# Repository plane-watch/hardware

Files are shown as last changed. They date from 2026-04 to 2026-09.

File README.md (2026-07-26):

# Plane Watch hardware

Open hardware designs from Plane Watch for receiving and decoding aircraft surveillance signals.

<div style="text-align: center;">Open Source Hardware Logo</div>

## Hardware projects

| Project | Preview Image | Description |
| --- | --- | --- |
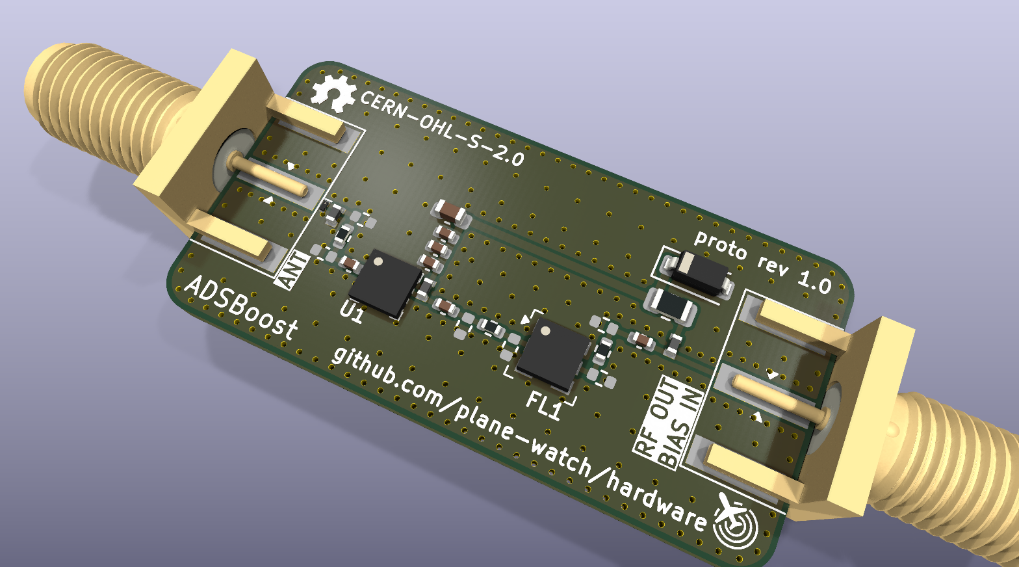
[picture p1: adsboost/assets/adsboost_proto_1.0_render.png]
3D render of the ADSBoost prototype revision 1.0 PCB
| [ADSBoost](adsboost/README.md) |  | A receive-only, bias-tee-powered low-noise amplifier and SAW filter module for 1,090 MHz ADS-B and Mode S reception. ADSBoost is designed to be installed close to the antenna; the current prototype is awaiting assembly and performance testing. |
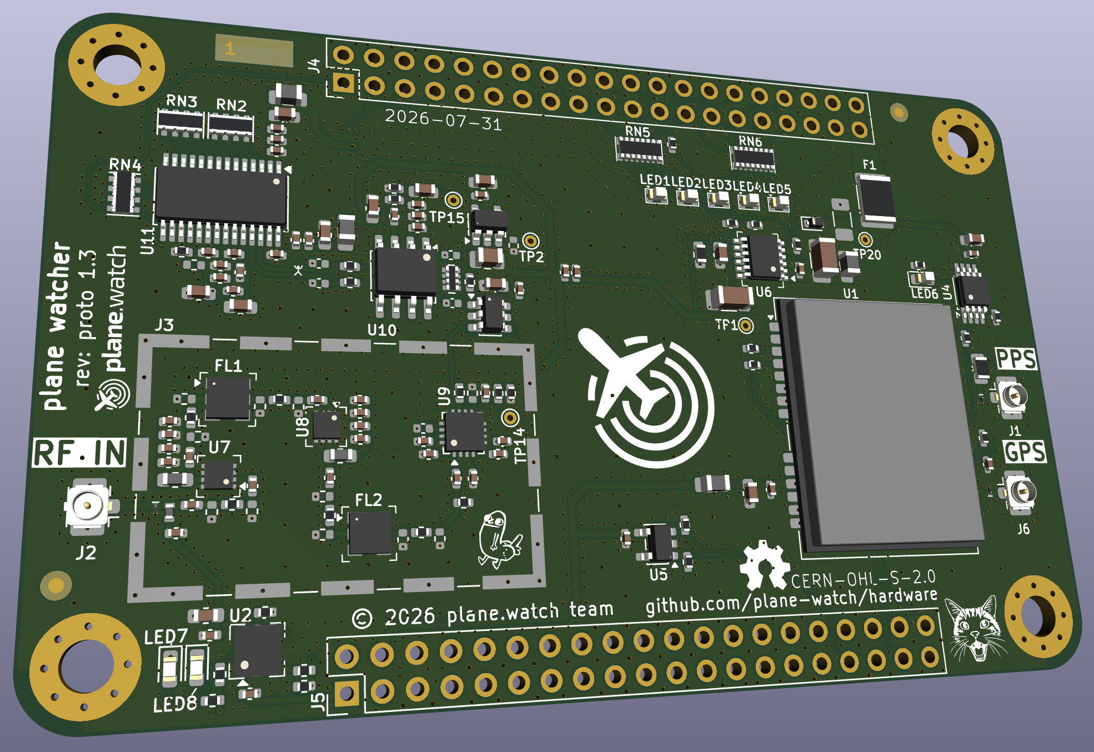
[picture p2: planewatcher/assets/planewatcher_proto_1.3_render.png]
3D render of the Plane Watcher prototype revision 1.3 PCB
| [Plane Watcher](planewatcher/README.md) |  | An open source, hardware-based ADS-B receiver and decoder for the HelloFPGA Smart ZYNQ SL. Plane Watcher combines a dual-stage RF front end, log detector, ADC and GNSS timing to support FPGA message decoding and accurate MLAT timestamping. |

## License

Unless a project or file explicitly states otherwise, all original hardware design files in this repository are licensed under the [CERN Open Hardware Licence Version 2 – Strongly Reciprocal (CERN-OHL-S-2.0)](LICENSE).

The CERN-OHL-S-2.0 permits commercial use, but its reciprocal requirements apply when covered source or products based on it are distributed. Alternative commercial licensing is available for organisations that need different terms.

In short: you may use and modify the designs privately. If you distribute modified source or products based on them, the CERN-OHL-S-2.0 requirements apply.

## Third-party materials disclaimer

This repository may include third-party datasheets, application notes and other technical documentation. These materials remain the copyright of their respective owners, are not covered by the repository's hardware licence, and are included solely to assist development and interoperability of the hardware projects.

If you are a copyright holder and have concerns about material included here, please open an issue or contact the maintainers.

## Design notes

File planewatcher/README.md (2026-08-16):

# plane watcher

Render of Plane Watcher PCB, prototype revision 1.3

The **plane watcher** is our attempt at creating an open source, hardware-based ADS-B receiver and decoder. It is a hat/cape/shield for a [HelloFPGA Smart ZYNQ SL](http://www.hellofpga.com/index.php/2023/05/10/smart-zynq-sl/) board.

The goal of the project is to make a reasonably priced yet high-quality ADS-B receiver for hobbyists. It is designed to support accurate MLAT timestamping using GNSS timing and message decoding in the FPGA.

This repository contains the hardware design. The FPGA gateware and software live in the [plane-watch/plane-watcher](https://github.com/plane-watch/plane-watcher) repository.

<div style="text-align: center;">Open Source Hardware Logo</div>

## Status

Proto 1.2 is the latest fabricated and tested revision. Proto 1.3 is still being refined and has not yet been fabricated or validated.

### Proto 1.2

The first fabricated prototype worked, but had a few issues:

- The SMA connector for the 1,090 MHz RF input fouled on the RJ45 Ethernet connector of the FPGA board. For proto 1.3, the RF and GPS antenna connectors have been swapped to U.FL. We will use pigtails to panel-mount SMA connectors.
- The ADL5513 log-detector output was not strong enough to drive the AD8138 ADC driver gain/feedback network directly. Increasing the gain/feedback resistor values from 499 Ω to 4.7 kΩ fixed this on the prototype. In proto 1.3, the ADL5513 output is also buffered.
- We did not have component footprints to tweak the ADL5513 output slope. These have been added to proto 1.3 to allow further refinement if required.
- The 1PPS LED was way too bright on the prototype, so this has been dimmed for proto 1.3.
- The ADL5513 TADJ trimmer network was too high impedance (I should've read the data sheet better) and did not appear to make any difference whatsoever. This has been replaced with a simple voltage divider set to around 0.86 V, in line with the datasheet guidance.

Regardless of the issues, we observed a reception range of approximately 320 km.

Animated GIF showing proto 1.2 in operation with blinky LEDs

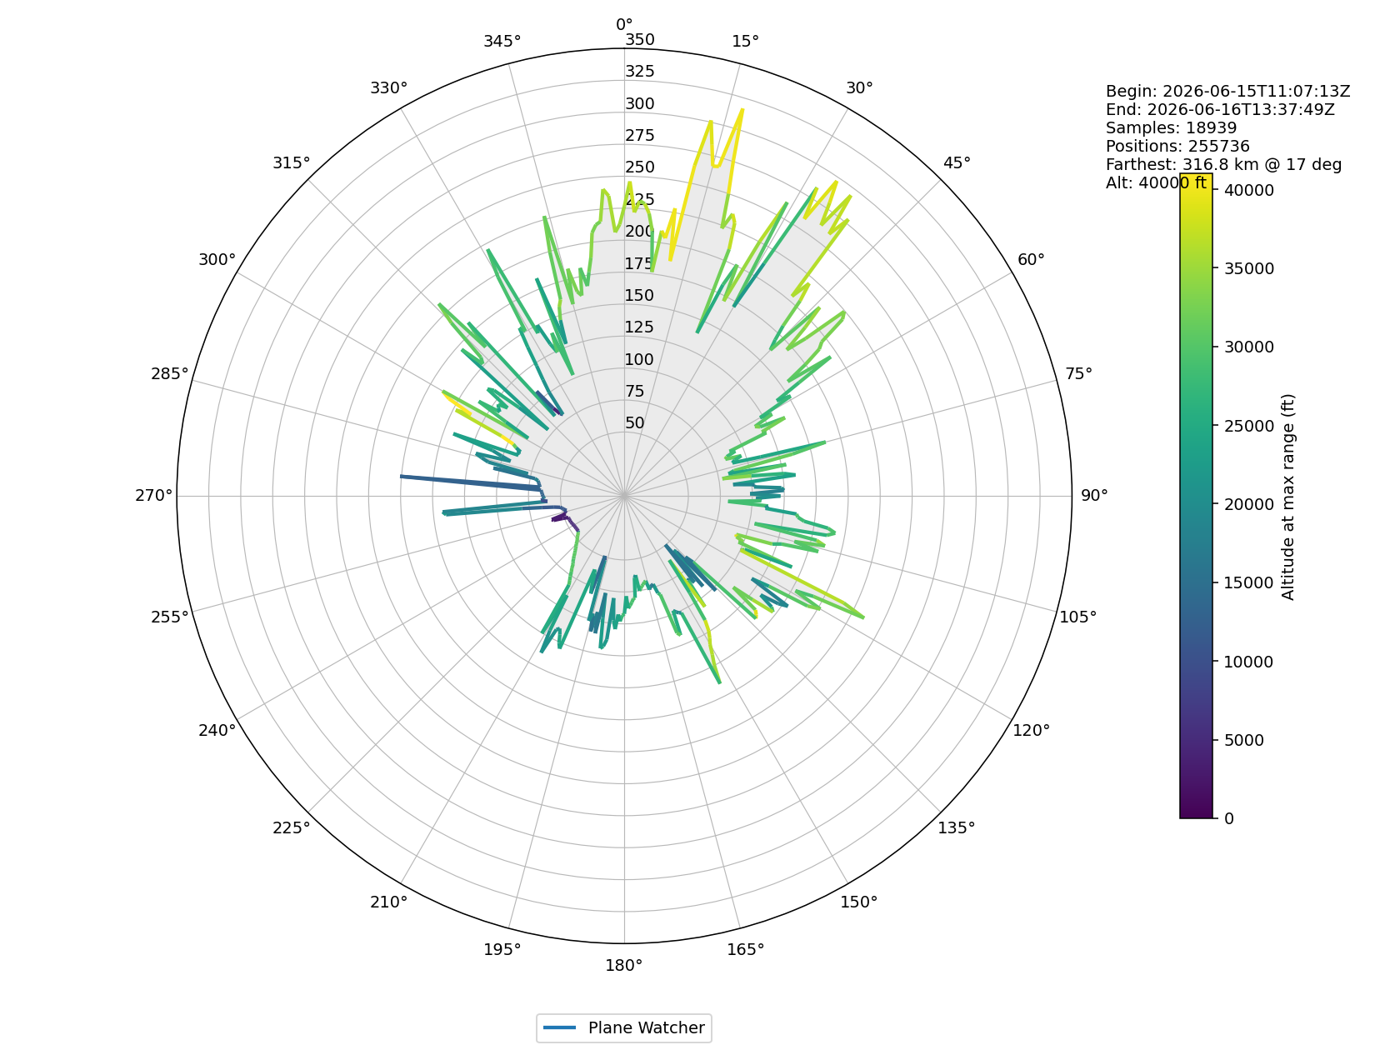
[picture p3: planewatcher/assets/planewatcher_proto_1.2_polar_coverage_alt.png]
Polar range diagram from proto 1.2


### Proto 1.3

In addition to fixing the issues above, proto 1.3 includes some functionality and layout changes:

- More unpopulated component footprints have been added to allow tweaking/refinement:
  - ADL5513 log-detector slope adjustment voltage divider.
  - AD8138 ADC driver feedback capacitors.
  - Five 0402 pi-pad matching networks along the RF path: one on each side of both LNA stages, and one at the ADL5513 RF input. These are fitted as straight-through links by default, with a 0 Ω series resistor and both shunt positions left unpopulated. After measuring the assembled board with a VNA, the footprints can be populated with suitable resistor, capacitor or inductor values to refine the 1,090 MHz matching and compensate for real-world PCB and component parasitics.
  - Other tweaking footprints along the ADC signal path.
- The ADL5513 log-detector output is buffered by a high-speed ADA4807-1 op-amp for more robust operation with weak signals, and to decouple it from the AD8138 input network.
- The buffered log-detector output is also fed into a first-order low-pass filter at approximately 0.072 Hz to produce a slow-moving analog baseline. This heavily attenuates short ADS-B pulse bursts, but sustained RF traffic can still affect the baseline. The baseline is buffered by an OPA320 and applied to the AD8138 ADC driver input network, offsetting the detector output before digitisation and improving the usable ADC range for weak pulses.
- RF_IN and GPS antenna connectors have been swapped from SMA to U.FL.
- A software-controlled bias tee has been added. This can supply around 4.5 V to the RF_IN connector, current-limited to approximately 300 mA. LEDs have been added to show whether bias tee is enabled/disabled, and to show if overcurrent disable has been activated.
- A GNSS-disciplined 1PPS timing output has been added. This is a buffered copy of the LEA-M8T TIMEPULSE signal, provided on a 50 Ω source-terminated U.FL connector. The centre pin carries an active-high pulse and the shell is connected to ground. The output is approximately 0 to 4.5 V into a high-impedance load, or approximately 0 to 2.2 V into a 50 Ω terminated load. The rising edge should be treated as the timing reference.
- Some discrete resistors have been replaced with resistor arrays to reduce the BoM and make hand assembly easier.
- The ADC supply, reference and VOCM networks have been reworked in an attempt to reduce noise, including additional bypassing, ferrite isolation and improved grounding.
- Selectable REFSENSE links allow the ADC input range to be configured for 1 Vpp or 2 Vpp.
- PCB grounding and sensitive-node isolation have been revised with additional via stitching, shorter reference routing and copper keepouts.
- Additional high-frequency bypassing has been added to keep the bias-tee supply side at RF ground.
- Re-routed ADC input differential pair to remove vias/crossovers & remove skew. The ADC output will need to be negated in software.

## Hardware overview

The proto 1.3 design has the following main components and interfaces:

| Function | Implementation |
| --- | --- |
| RF input | 1,090 MHz ADS-B, U.FL connector |
| RF front end | Two LNA and SAW filter stages |
| Log detector | ADL5513 |
| Baseband buffers | ADA4807-1 fast-path buffer and OPA320 slow-baseline buffer |
| ADC driver | AD8138 |
| ADC | AD9203, 10-bit, up to 40 MSPS |
| GNSS timing | LEA-M8T with FPGA and external 1PPS outputs |
| Bias tee | Software-controlled, approximately 4.5 V at 300 mA maximum |
| Local power | LT3045-1 low-noise 3.3 V RF/analog supply |
| FPGA carrier | HelloFPGA Smart ZYNQ SL |

## Design

The design consists of the following parts:

### RF Input

The signal from the antenna is amplified and filtered using two stages of LNA amplification and SAW filters centred on 1,090 MHz.

A switchable bias tee power supply can apply approximately 4.5 V at up to 300 mA to the RF_IN connector.

### Log Detector

The amplified and filtered RF signal is fed into an ADL5513 log detector, which produces a voltage proportional to the logarithm of the RF input power. With an oscilloscope on its output, we can see the raw ADS-B pulses and decode them by hand.

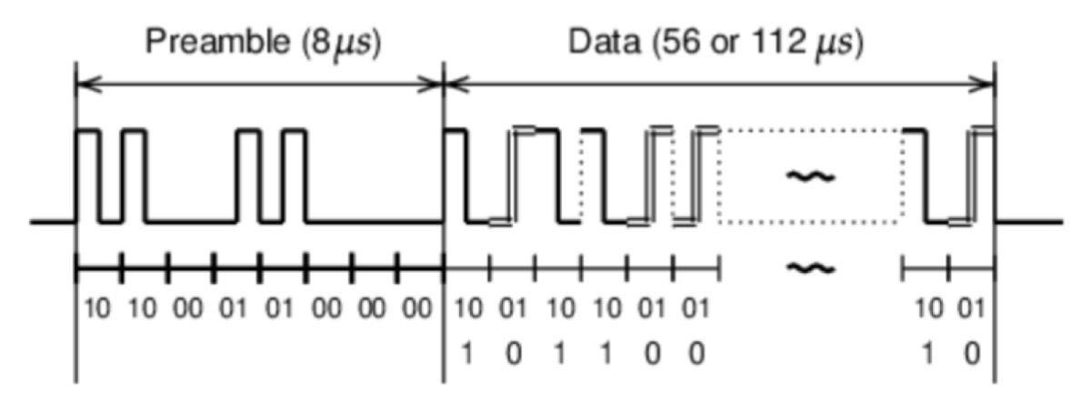
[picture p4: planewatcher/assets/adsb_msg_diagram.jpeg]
ADS-B message example diagram


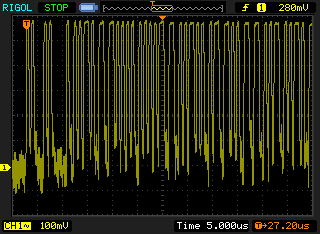
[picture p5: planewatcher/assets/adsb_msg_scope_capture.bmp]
ADS-B message pulses on an oscilloscope


### ADC Driver

The ADL5513 log-detector output is buffered with a high-speed ADA4807-1 op-amp to isolate it from the ADC driver input network and provide a robust baseband signal.

The ADC uses a differential input. To drive it, the buffered baseband signal is split:

- Through the gain/input resistor network into the AD8138 positive input summing node.
- Into a first-order low-pass filter at approximately 0.072 Hz, producing a slow-moving analog baseline with short ADS-B pulse bursts heavily attenuated. This baseline is then buffered by an OPA320 to decouple it from the ADC driver input network and applied through the gain/input resistor network into the AD8138 negative input summing node.

The AD8138 produces a differential output proportional to the difference between the instantaneous log-detector output and the slow noise-floor estimate.

### ADC

The differential output of the ADC driver is fed into an AD9203 10-bit, 40 MSPS ADC. The ADC input range can be configured for 1 Vpp or 2 Vpp using selectable REFSENSE links. After prototyping we will either hard-set this, or make it software controllable. The FPGA supplies the sample clock and receives the digitised output.

### GNSS Timing

The LEA-M8T GNSS timing receiver provides its TIMEPULSE signal to the FPGA for timestamping. Proto 1.3 also buffers this signal for an external, source-terminated 1PPS output and a status LED.

### Power

The board is powered from the approximately 4.5 V FPGA_VCC rail provided by the carrier board (5V from the USB-C connector, through a Schottky diode). The input has resettable overcurrent and transient protection. A ferrite-filtered LT3045-1 linear regulator generates the local low-noise 3.3 V RF/analog supply, with additional ferrite isolation and local bypassing around the ADC.

### FPGA

The FPGA gateware samples the ADC output, detects and timestamps ADS-B pulses, and converts them into usable messages. The gateware and supporting software are developed in the [plane-watch/plane-watcher](https://github.com/plane-watch/plane-watcher) repository.

## Repository contents

- [KiCad project](planewatcher/kicad/planewatcher.kicad_pro)
- [Top-level schematic](planewatcher/kicad/planewatcher.kicad_sch)
- [PCB layout](planewatcher/kicad/planewatcher.kicad_pcb)

The editable design files use KiCad 10. Release-ready manufacturing outputs are not currently included while the proto 1.3 design is still being refined.

## Attributions

- [“1.09 GHz Mode-S Receiver Design and
  VHF Radar Antenna Characterization”, Senior Thesis in Electrical Engineering, Dabin Zhang](https://www.ideals.illinois.edu/items/47640/bitstreams/139976/data.pdf).
- [Project “ADS-B Receiver and Decoder” presentation by Günter Köllner, DL4MEA](https://www.qsl.net/dl4mea/fpgaadsb/Koellner_Projekt-ADSB3.pdf).
- The [Open Source Hardware gear logo](https://oshwa.org/resources/open-source-hardware-logo/) was designed by Macklin Chaffee and is licensed CC-SA.
- “Dickbutt” appears courtesy of [K.C. Green](https://kcgreendotcom.com/). RF performance gains are unverified.

## License

The hardware design files are licensed under the [CERN Open Hardware Licence Version 2 – Strongly Reciprocal (CERN-OHL-S-2.0)](LICENSE).

The CERN-OHL-S-2.0 permits commercial use, but its reciprocal requirements apply when covered source or products based on it are distributed.

Alternative commercial licensing is available for companies that need different terms.

TL;DR: You can use and modify the design privately. If you distribute modified source or products based on it, the CERN-OHL-S-2.0 requirements apply. If those terms do not work for you, talk to us.

## Notice

This repository may include third-party datasheets, application notes, and technical documentation.

Such materials remain the copyright of their respective owners and are included solely to assist development and interoperability of this project.

If you are a copyright holder and have concerns regarding included materials, please open an issue or contact the maintainers.

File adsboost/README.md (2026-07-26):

# ADSBoost

3D render of the ADSBoost prototype revision 1.0 PCB

**ADSBoost** is an open source, receive-only LNA and SAW filter module for 1090 MHz ADS-B and Mode S reception. It is intended to be installed close to the antenna and powered through its RF output coax using a bias tee.

<div style="text-align: center;">Open Source Hardware Logo</div>

## Expected performance

> ADSBoost is currently a prototype. The module-level figures below are design estimates derived from the component datasheets; they are not production-tested. They will be replaced with measured results after the first assembled boards have been characterised.

| Parameter | Expected performance | Notes |
| --- | --- | --- |
| Application | 1090 MHz ADS-B and Mode S reception | Receive only; do not connect the input to a transmitter |
| Centre frequency | 1090 MHz | Set by the TA2003A SAW filter |
| Specified passband | 1087-1093 MHz | 6 MHz nominal filter bandwidth |
| In-band gain | Approximately 15 dB typical | Estimated from approximately 18 dB LNA gain at 1090 MHz minus 3.2 dB typical SAW insertion loss and small PCB losses |
| Noise figure | Approximately 0.5-0.7 dB expected | Estimate including the input network; measurement pending |
| RF impedance | 50 ohms nominal | Both ports |
| Operating temperature | -40 to +85 degrees C design range | Limited by the SAW filter; module not yet environmentally qualified |
| Supply voltage | See [Powering ADSBoost](#powering-adsboost) | DC is supplied through the RF output connector |
| Supply current | Approximately 45-68 mA typical | Depends on supply voltage; allow at least 100 mA from the bias tee |

The [Qorvo TQP3M9036](<datasheets/TQP3M9036 Data Sheet.pdf>) LNA has approximately 18.4 dB typical gain and 0.42 dB minimum noise figure around 1090 MHz when operated from 5 V. The [TA2003A datasheet](<datasheets/TA2003A _Rev.1.0_.pdf>) specifies 3.2 dB typical and 4.0 dB maximum insertion loss across 1087-1093 MHz.

The SAW filter also specifies the following out-of-band attenuation. These are component specifications rather than measured module limits.

| Frequency range | Minimum attenuation |
| --- | ---: |
| DC-970 MHz | 45 dB |
| 1046 MHz | 40 dB |
| 1150-1300 MHz | 45 dB |

Module input/output return loss, gain variation, compression point and linearity remain to be measured on assembled hardware.

## RF matching and tuning

Three 0402 pi-pad matching networks are provided along the RF path: one at the LNA input, one between the LNA and SAW filter, and one after the SAW filter. They are fitted as straight-through links by default, with a 0 ohm series resistor and both shunt positions left unpopulated.

After assembled boards have been measured with a VNA, the footprints can be populated with suitable resistor, capacitor or inductor values to refine the 1090 MHz matching and compensate for real-world PCB and component parasitics.

## Connections

| Connector | Function |
| --- | --- |
| `J1` / `ANT_IN` | RF input from the antenna; no DC should be applied here |
| `J2` / `RF_OUT+BIAS` | Amplified and filtered RF output, and positive DC bias input |

## Powering ADSBoost

ADSBoost is powered through `J2` using a bias tee. The coax centre conductor must be positive and the shield must be ground. The bias tee should present the DC supply on its RF+DC port while preventing that DC from reaching the receiver's RF input.

The [TQP3M9036 datasheet](<datasheets/TQP3M9036 Data Sheet.pdf>) specifies:

| LNA operating point | Device supply current |
| --- | ---: |
| 3.3 V | Approximately 45 mA typical |
| 4.0 V | Approximately 50 mA typical |
| 5.0 V | Approximately 68 mA typical; 40-90 mA datasheet range |

The LNA's recommended device supply range is **3.3-5.25 V**. ADSBoost includes a 1 ohm series protection/filter resistor, which introduces a small voltage drop. Therefore:

- Supply **3.4-5.0 V DC at `J2`**, with 5.0 V recommended.
- Use a low-noise, regulated supply capable of at least **100 mA**.
- Treat all stated voltages as voltages at the module. Coax and bias-tee resistance may produce an additional voltage drop.
- Do not apply DC to `J1`.
- Do not reverse the supply polarity.

### Overvoltage warning

The board includes a [BZT52C6V2](https://www.diodes.com/part/view/BZT52C6V2/) 6.2 V zener diode and a 1 ohm series resistor to help clamp short transients. **This circuit is not a voltage regulator and does not make sustained overvoltage safe.**

Do not exceed the LNA's 5.25 V recommended operating limit. Its 7 V absolute maximum rating is a damage threshold, not an acceptable supply voltage. A sustained excessive voltage can overheat or destroy the zener diode, series resistor and LNA. In particular, applying 12 V through a common masthead-amplifier bias supply is likely to damage the module.

## Enclosure

ADSBoost is designed to fit either of these 100 mm split aluminium enclosures from JLCMC:

- [Aluminum Box (JLC) – 25 × 25 × 40 mm, Split (K1-2525-H6-L40), Natural](<https://jlcmc.com/product/b/U01/BR12070/aluminum-box-(jlc)-25*25*100mm-split>)
- [Aluminum Box (JLC) – 25 × 25 × 40 mm, Split (K1-2525-H7-L40), Black](<https://jlcmc.com/product/b/U01/BR12071/aluminum-box-(jlc)-125*25*100-split>)

Installation requires one **6.6 mm diameter hole in the centre of each end cap**, aligned with the RF connectors.

## License

The hardware design files are licensed under the [CERN Open Hardware Licence Version 2 – Strongly Reciprocal (CERN-OHL-S-2.0)](LICENSE).

The CERN-OHL-S-2.0 permits commercial use, but its reciprocal requirements apply when covered source or products based on it are distributed.

Alternative commercial licensing is available for companies that need different terms.

TL;DR: You can use and modify the design privately. If you distribute modified source or products based on it, the CERN-OHL-S-2.0 requirements apply. If those terms do not work for you, talk to us.

## Notice

This repository may include third-party datasheets, application notes, and technical documentation.

Such materials remain the copyright of their respective owners and are included solely to assist development and interoperability of this project.

If you are a copyright holder and have concerns regarding included materials, please open an issue or contact the maintainers.

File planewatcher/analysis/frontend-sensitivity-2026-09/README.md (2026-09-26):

# Rev 1.3 frontend sensitivity: finding and fix (September 2026)

## Summary

The rev 1.3 receiver was about **3 dB less sensitive than a Mode-S Beast** on
the same conducted stimulus. The analogue frontend was not the cause. The
preamble detector's **absolute power threshold (2000 at 32 MS/s)** rejected
weak frames that the ADC samples still carried cleanly. Its **32 µs holdoff**
also let every false trigger blank real frames.

Setting `power_threshold` to **700** and the holdoff to **8 µs** moved the
conducted decode knee to within **0.5 dB of the Beast**, with no noise
triggers on a terminated input. On air at the usual site, the median maximum
range per bearing rose from **76 km to 164 km**, and coverage is now roughly
level with a Radarcape that used the same site and antenna. The new values
are the bitstream reset defaults on software `main` (commit `f842867`).

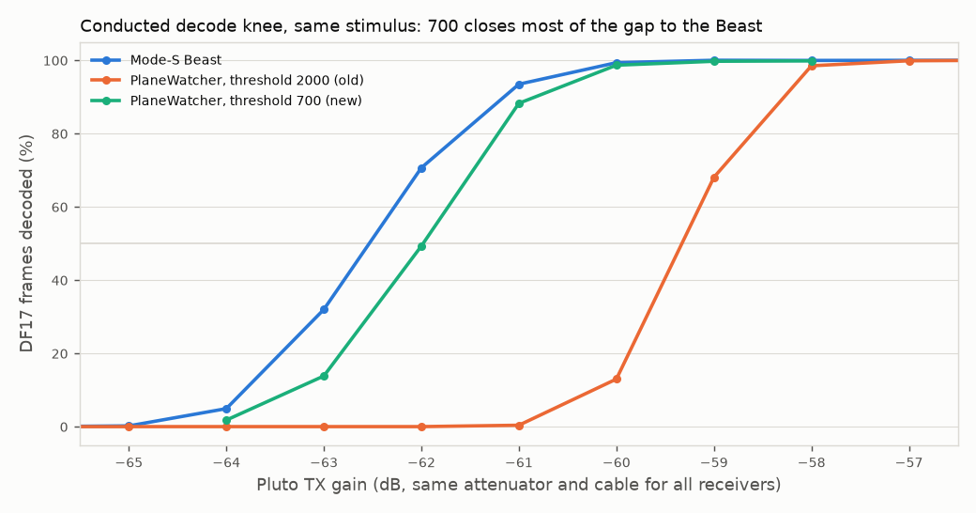
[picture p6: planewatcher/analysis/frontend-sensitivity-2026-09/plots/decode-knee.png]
Decode knee


## How it was localised

1. **The ADC samples carry the bits past the knee.** At the level where
   PlaneWatcher decoded 0.4% of frames (and the Beast 93%), raw ADC captures
   still separated every PPM bit at μ/σ ≈ 4.7; 34/34 bits of one window
   matched the transmitted frame. An ideal decision on those samples reaches
   50% about 5 dB lower than PlaneWatcher did. The loss was after the ADC
   ([data/adc-bit-margin-20260923.json](data/adc-bit-margin-20260923.json),
   [plots/adc-window-61.png](plots/adc-window-61.png)).
2. **The first preamble gate rejects them.** The FPGA's per-stage counters
   showed thousands of pulse edges at −61/−62 dB. Only 969 and 4 detections
   passed the absolute power threshold; the quiet-zone and SNR gates passed
   nearly everything that reached them
   ([data/sweeps/funnel.json](data/sweeps/funnel.json)).
3. **The threshold closes the gap.** 50% decode point (Pluto gain; the same
   attenuator and cable for every receiver). "Idle" counts detections in 10 s
   with the source off:

   | `power_threshold` | 50% point | vs Beast (−62.53) | idle detections, 10 s |
   | ---: | ---: | ---: | ---: |
   | 2000 (old) | −59.35 | 3.2 dB worse | 0 |
   | 1000 | −61.19 | 1.3 dB worse | 0 |
   | **700** | **−61.98** | **0.55 dB worse** | **0** |
   | 500 | −62.69 | level | 13 (2 junk messages) |

4. **The holdoff, not decoder occupancy, loses frames to false triggers.**
   After any detection the detector ignores new preambles for the holdoff.
   A load test injected valid frames plus bare preambles, never overlapping
   on air. Loss followed holdoff blanking, not exhaustion of the 8 decoder
   slots ([data/sweeps/load/](data/sweeps/load/),
   [data/sweeps/holdoff/](data/sweeps/holdoff/)):

   | False triggers/s | 32 µs (old) | **8 µs** | 120 µs |
   | ---: | ---: | ---: | ---: |
   | 2,660 | 92.9% | **99.9%** | 72.9% |
   | 8,800 | 85.2% | **99.9%** | 51.5% |

   The cost of 8 µs is more payload retriggers: about 12 detections per long
   frame instead of 4, filtered on the PS side. Modelled, 8 decoders reach
   about 1% blocking near 2,000 long frames/s. More decoder slots and early
   release of hopeless candidates would restore margin.

## On-air result

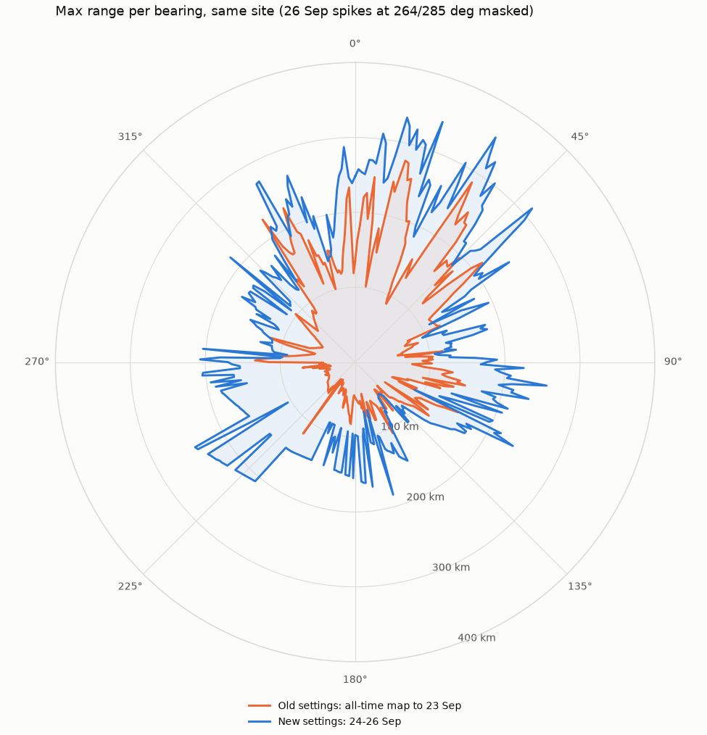
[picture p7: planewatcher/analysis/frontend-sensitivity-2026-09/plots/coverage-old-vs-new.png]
Coverage, old vs new settings

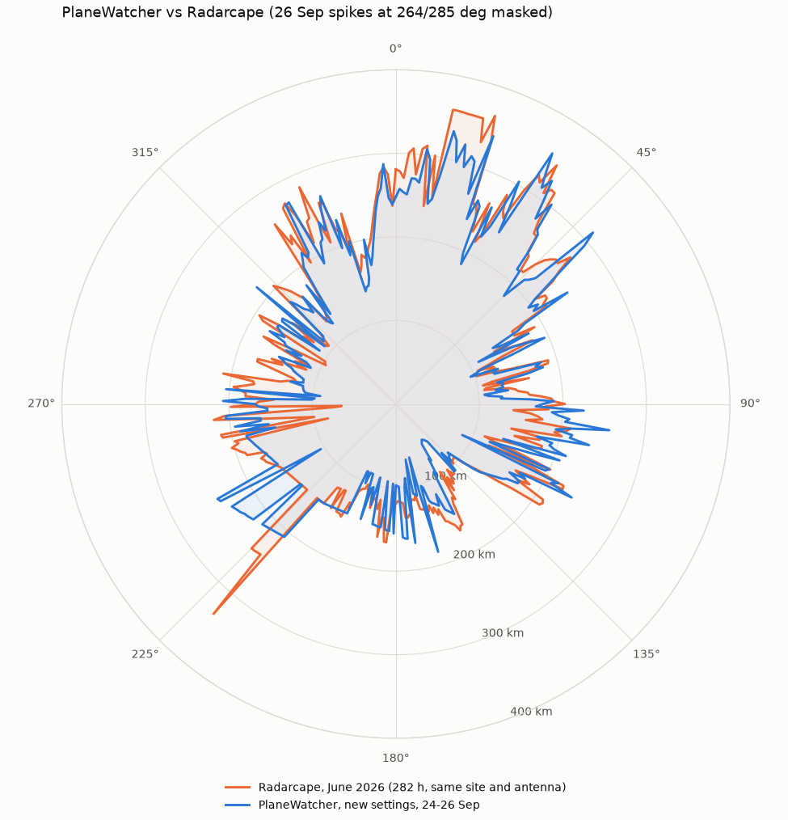
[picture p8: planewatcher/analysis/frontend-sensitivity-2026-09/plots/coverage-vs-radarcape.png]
Coverage vs Radarcape


| Sector median | Old settings (all-time) | New settings (24–26 Sep) | Radarcape, June |
| --- | ---: | ---: | ---: |
| North 330–30° | 166 km | 249 km | 257 km |
| East 60–120° | 95 km | 172 km | 163 km |
| South 150–210° | 56 km | 123 km | 130 km |
| West 240–300° | 49 km | 157 km | 166 km |

Caveats:

- This is not a controlled A/B. The traffic and accumulation times differ,
  and about 18 h of the new-settings window ran on the old settings after a
  firmware slot switch dropped the runtime override.
- Two 26 September bins (264° and 285°, 603 and 566 km) lie beyond the radio
  horizon for their altitudes. They are bad position decodes and are masked
  in the plots.
- Radarcape figures come from its hourly range files; 282 of June's 696
  hours were available.
- The coverage data holds bearing, range and altitude only.

## Ruled out along the way

- **Input matching:** measured mismatch loss at the antenna input is about
  0.3 dB. Z13 = 68 nH is a small, real improvement, and a second 68 nH at Z15
  added about 0.07 dB. Matching cannot recover dB-scale sensitivity.
- **Detector noise floor and pre-detector gain:** the ADL5513's own noise
  dominates the floor power, but after video filtering it acts as a benign
  pedestal. Modelled, 10 dB of extra gain or a reactive detector match
  changes detectability by less than 0.5 dB
  ([data/noise-floor-model.json](data/noise-floor-model.json)).
- **FL2 / detector interface:** worst case about 1 dB of post-LNA level,
  which does not affect SNR. An unexplained ~10 dB return loss measured
  through a temporary coax was not pursued further.
- **Long feed runs matter:** cable loss before the first LNA subtracts
  directly from sensitivity (LMR-200 is about 0.57 dB/m at 1090 MHz). Use
  the bias tee and a mast-head LNA for long runs.

## Bench notes worth keeping

- Pluto clones can fail their boot-time AD9361 interface tune. When that
  happens, buffered TX is silent but the DDS still works. The software repo's
  Pluto tools now refuse to transmit when the RX core is missing; reboot the
  Pluto.
- Receiver-side debug counters (`/api/stats?debug=1`) localise decode losses
  far faster than VNA work on internal nodes.

## Contents

- `data/sweeps/`: decode-rate sweeps (Beast, PlaneWatcher), threshold,
  load and holdoff tests, with per-stage FPGA counter deltas.
- `data/coverage/`: coverage snapshots (bearing, km, altitude) and the
  Radarcape June reduction.
- `data/adc-bit-margin-*.json`, `data/noise-floor-model.json`: ADC
  bit-margin and detector-noise analyses. The raw captures are not committed.
- `scripts/`: `make_plots.py` regenerates the plots from `data/`.
  `compare_coverage.py`, `fetch_radarcape_range.py`, `adc_bit_margin.py`,
  `noise_floor_analysis.py` and `plot_adc_window.py` are the analysis tools;
  the last three need raw captures.

The bench tooling (Beast, HackRF and Pluto sweeps, decoder-load generator,
on-air A/B) lives in the software repository under `tools/`.

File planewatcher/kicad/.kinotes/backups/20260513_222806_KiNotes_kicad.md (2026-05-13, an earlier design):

# **kicad - Design Notes**

## **Overview**
<!-- Brief description of the PCB project -->

## **Schematic Notes**
<!-- Key circuit blocks, design rationale -->

## **Layout Considerations**
<!-- Layer stackup, impedance, keep-outs -->

## **Component Notes**
<!-- Click on designators like R1, C5, U3 to highlight on PCB -->

## **Power Distribution**
<!-- Power rails, decoupling strategy -->

## **Signal Integrity**
<!-- Critical nets, routing constraints -->

## **References**
<!-- Datasheets, application notes, calculations -->

## **TODO**
- LT3045‑1 PGFB tied to VPRE (pin 7 → /Power_5V_RF/VPRE, etc.). The user note confirms intent: "PG = VPRE good, 0 = no input power." That's diagnostically weak — PG just echoes input presence, not whether the LDO is in regulation. For ~zero extra cost, tying PGFB to a fraction of OUT via a divider would make PG signal real output regulation. Up to you whether that matters for this project.
- **LT8640**‑1 SYNC/MODE floating (U12 pin 17) — datasheet allows this for the ‑1 variant (defaults to FCM), but it leaves spread‑spectrum disabled on the FPGA rail. Inconsistent with the LT8608 stages which use SSFM. Tying SYNC/MODE
   to INTVcc (pin 2) via 0 Ω would extend SSFM coverage to U12. Probably not impactful because the FPGA load isn't on the RF path, but cheap to add.
  8. LT8608 EN/UV tied directly to VIN. Functionally fine (always enabled while VIN > ~1 V EN threshold), but you've thrown away the precise programmable UVLO. A 2‑resistor divider would give a clean turn‑on point (e.g. 8 V) —
  useful if you want a deterministic startup on a slow 12 V rise. Optional.

---
*KiNotes - PCBtools.xyz*

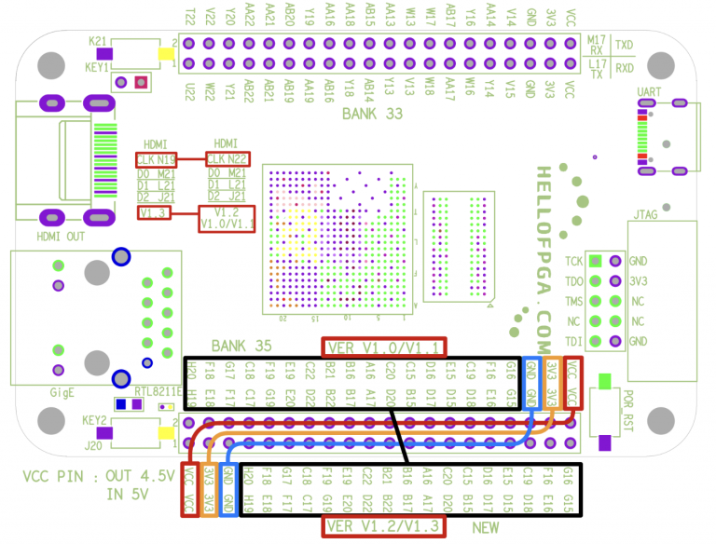
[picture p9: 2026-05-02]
planewatcher/datasheets/Smart_ZYNQ_SL_SIZE_20230510_pinout.png

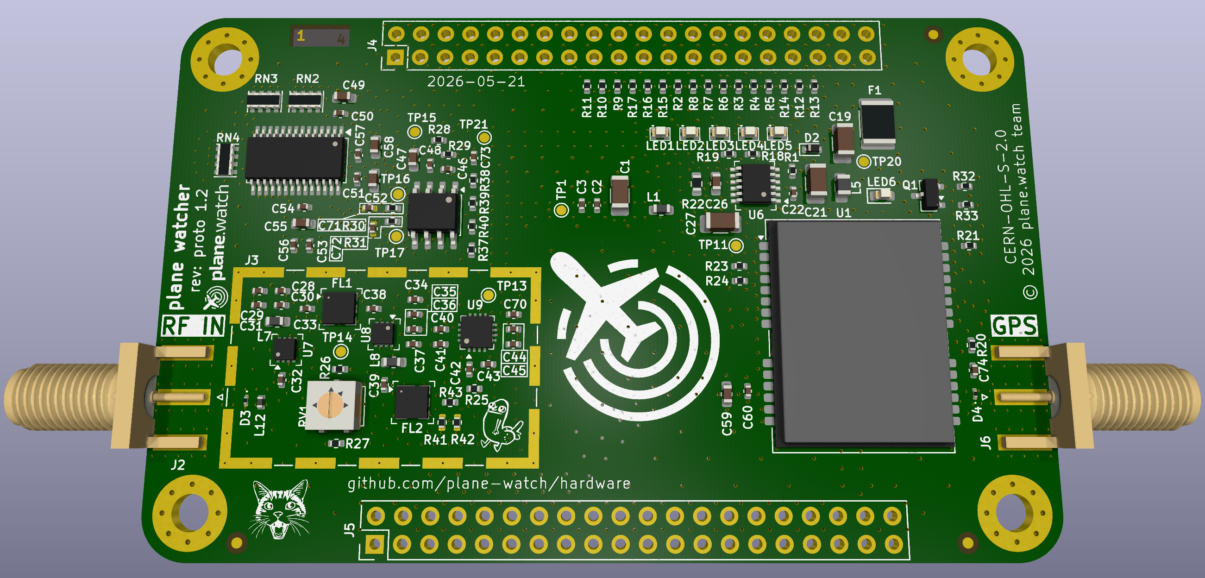
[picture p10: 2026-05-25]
planewatcher/assets/planewatcher_proto_1.2_render.png

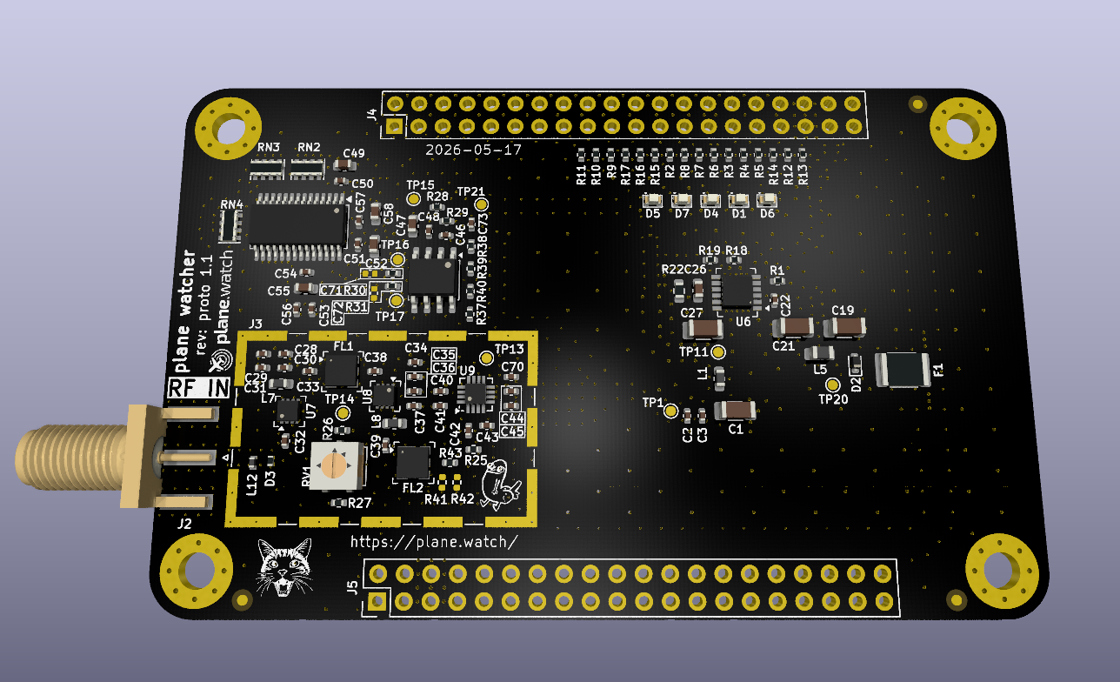
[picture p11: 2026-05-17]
planewatcher/assets/planewatcher_proto_1.1_render.png

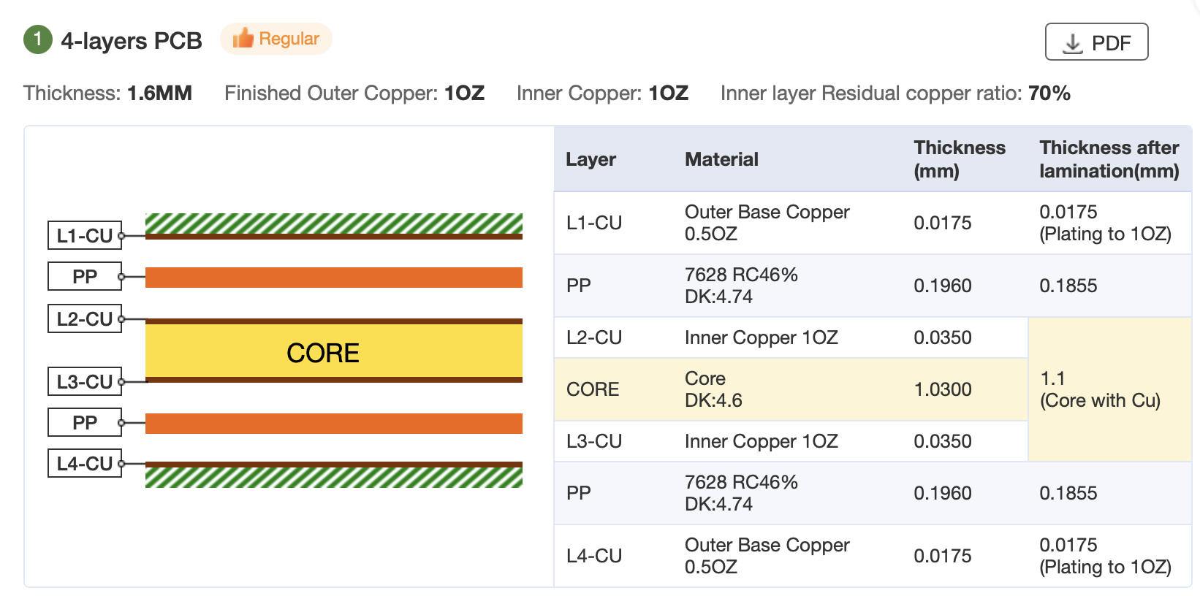
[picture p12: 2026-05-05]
planewatcher/PCBWay Stackup.png

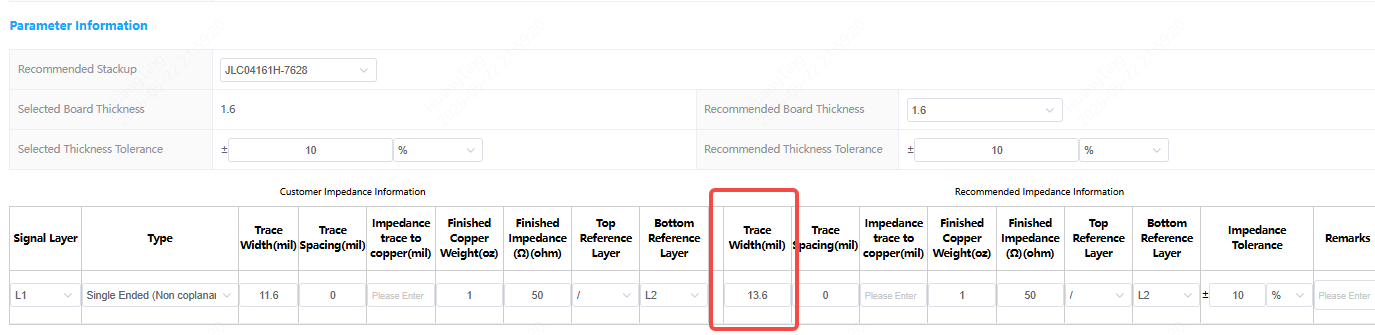
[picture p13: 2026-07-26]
planewatcher/JLCPCB_Impedance_Calc.png

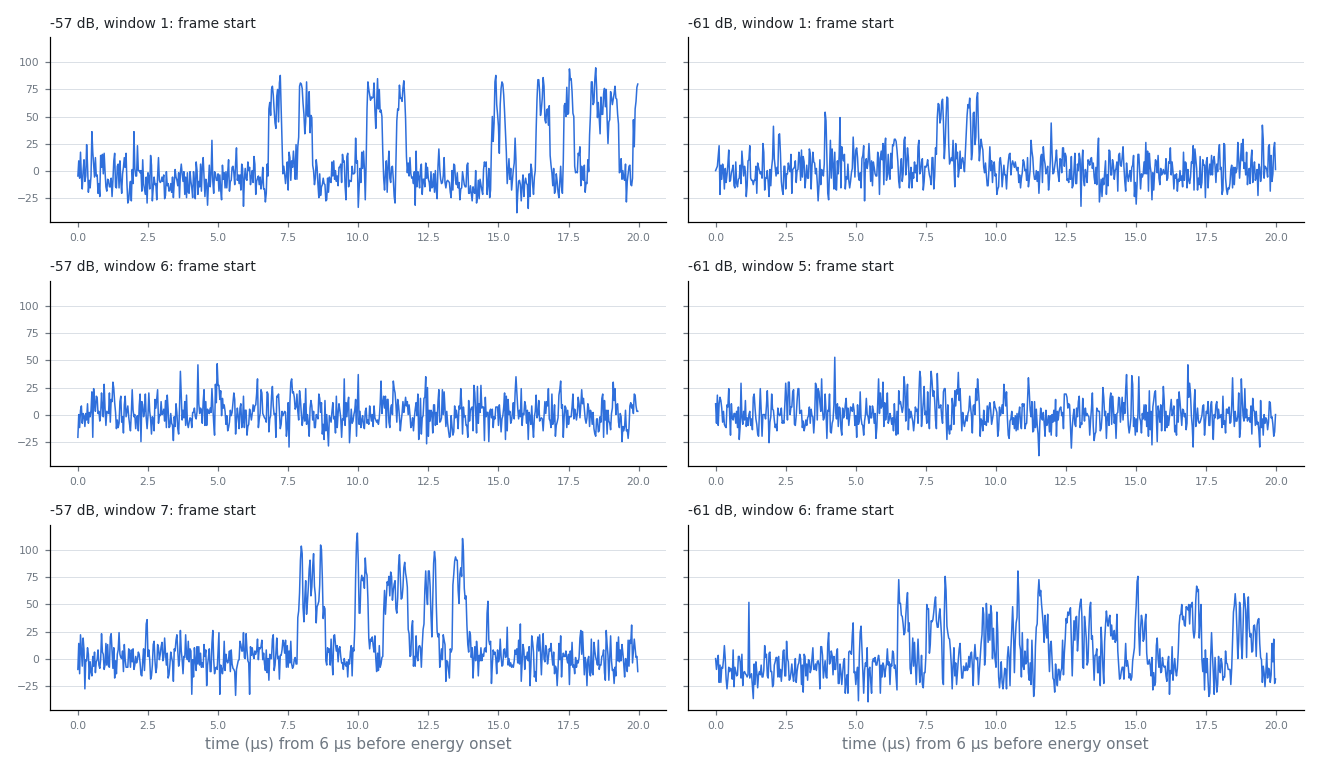
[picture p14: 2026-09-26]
planewatcher/analysis/frontend-sensitivity-2026-09/plots/adc-frame-starts.png

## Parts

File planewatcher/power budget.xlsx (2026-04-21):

Device | Purpose | Draw on 5V rail (mA) | Draw on 3V3 rail (mA) | Draw on 1V65 rail (mA) | Quantity | Total draw on 5V rail (mA) | Total draw on 3V3 rail (mA) | Total draw on 1V65 rail (mA)
TQP3M9036 | General power | 90 | 0 | 0 | 2 | 180 | 0 | 0
TQP3M9036 | Shutdown pin | 0.14 | 0 | 0 | 2 | 0.28 | 0 | 0
ADL5513 | General power | 31 | 0 | 0 | 1 | 31 | 0 | 0
AD8138 | General power | 23 | 0 | 0 | 1 | 23 | 0 | 0
AD9238 | AVDD | 0 | 200 | 0 | 1 | 0 | 200 | 0
AD9238 | DRVDD | 0 | 14 | 0 | 1 | 0 | 14 | 0
 |  |  |  |  | TOTALS | 234.28 | 214 | 1

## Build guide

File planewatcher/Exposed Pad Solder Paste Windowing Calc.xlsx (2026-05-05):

Pad Width | 1.651 | mm
Pad Height | 2.845 | mm
Cols | 2
Rows | 2
Padding | 0.15 | mm
Horiz. Padding Amount | 0.45
Vert. Padding Amount | 0.45
Window Width | 0.601
Window Height | 1.198
Pad Area | 4.697095 | mm2
Window Area | 2.876395 | mm2
Coverage | 61.23774375%

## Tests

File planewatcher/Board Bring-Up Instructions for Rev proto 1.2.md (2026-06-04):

# Board Bring-Up Instructions: Rev proto 1.2

## Safety Notes

* Use ESD precautions when handling U7, U8, U9, U10, U11, and U1.
* Do not attach or remove the FPGA board while either board is powered.
* Remove power and confirm the rails have discharged before fitting components or changing board connections.
* For board-only testing, use a current-limited bench supply:
  * Start with the supply set to 0V.
  * Suggested first power-up limit, with U7, U8, U9, U10, U11, and U1 removed: 100mA.
  * Suggested second power-up limit, after fitting U7, U8, U9, U10, and U11: 300mA.
  * Record the steady-state current at each stage. Increase the limit only if the measured current is understood.
* Stop immediately if the supply hits current limit, a rail collapses, a measured voltage is out of tolerance, or any IC/regulator becomes hot.
* Use a DMM or 10x high-impedance oscilloscope probe for TP13, TP16, TP17, and TP21. Do not use 50 ohm scope termination on these points.

## Visual Checks

### Check Soldering

* Where possible, check solder joints under microscope and ensure no dry joints.
* Ensure no tombstoned components.

### Component Orientation

With the board oriented component side up, and the RF_IN connector facing left:

* U7 pin 1 should be bottom side, leftmost pin
* FL1 pin 1 should be left side, topmost pin
* U8 pin 1 should be top side, rightmost pin
* FL2 pin 1 should be left side, topmost pin
* U9 pin 1 should be bottom side, leftmost pin
* U10 pin 1 should be top side, rightmost pin
* U11 pin 1 should be top side, rightmost pin
* LED1-5 common anode (+) should be top side, leftmost pin
* U6 pin 1 should be right side, bottommost pin
* Q1 pin 1 (gate) should be bottom pin
* LED6 anode (+) should be left pin
* U1 module pin 1 should be left side, topmost pin

All other components should not be polarised.

## Board Bring-Up

### Before First Power-Up

* Remove expensive components before first bring-up:
  * U7 LNA, TQP3M9036
  * U8 LNA, TQP3M9036
  * U9 log detector, ADL5513
  * U10 ADC driver, AD8138
  * U11 ADC, AD9203
  * U1 GPS module
* Do not attach to the FPGA board.
* Resistance checks, with the board unpowered: ensure there are no dead shorts or unexpectedly low resistance readings.
  * Place black probe on pin 36 of connector J4 (GND)
  * Check resistance to:
    * pin 38 of connector J4 (FPGA_3V3)
    * pin 40 of connector J4 (FPGA_VCC)
    * TP20 (5V input)
    * TP11 (3V3)
    * TP1 (3V3A)
    * TP14 (TADJ)
    * TP15 (VOCM)
  * The reading may move while capacitors charge. The check is for a hard short or low-ohm fault, not necessarily a perfect open circuit.

### First Power-Up

* Apply power to board
  * GND to pin 35/36 of connector J4
  * Current-limited 5V to pin 39/40 of connector J4
  * Start at 0V, current limit 100mA, then ramp up to 5V
  * Stop immediately if the supply reaches current limit, a rail is low, or anything heats unexpectedly
* Multimeter checks: check voltages
  * Place black probe on pin 36 of connector J4 (GND)
  * Set to DC voltage
  * Place red probe on TP20, ensure 5V
  * Place red probe on TP11, ensure 3.3V
  * Place red probe on TP1, ensure 3.3V
  * Place red probe on TP14, ensure about 0.80V to 0.87V
  * Place red probe on TP15, ensure about 1.65V
  * Record the input current
* Remove power

### Replace removed components

* U7 LNA
* U8 LNA
* U9 Log Detector
* U10 ADC Driver
* U11 ADC
* Leave U1 GPS module removed.
* Leave FPGA board disconnected.
* Inspect the newly fitted parts under microscope before applying power.
* Repeat resistance checks, with the board unpowered:
  * Place black probe on pin 36 of connector J4 (GND)
  * Check TP20, TP11, TP1, TP14, TP15, and TP21
  * Ensure there are no dead shorts or unexpectedly low resistance readings

### Second Power-Up

* Apply power to board
  * GND to pin 35/36 of connector J4
  * Current-limited 5V to pin 39/40 of connector J4
  * Start at 0V, current limit 300mA, then ramp up to 5V
  * Stop immediately if the supply reaches current limit, a rail is low, or anything heats unexpectedly
  * U11 digital outputs are unloaded while the FPGA board is disconnected. This should not damage U11.
* Multimeter checks as before: check voltages
  * Place black probe on pin 36 of connector J4 (GND)
  * Set to DC voltage
  * Place red probe on TP20, ensure 5V
  * Place red probe on TP11, ensure 3.3V
  * Place red probe on TP1, ensure 3.3V
  * Place red probe on TP14, ensure about 0.80V to 0.87V
  * Place red probe on TP15, ensure about 1.65V
* New multimeter checks: check voltage
  * Place black probe on pin 36 of connector J4 (GND)
  * Set to DC voltage
  * Check TP21 with a DMM or 10x high-impedance probe only. Ensure about 1V.
* Scope checks
  * Optimum TADJ voltage
    * Connect probe ground to board ground
    * Probe TP13 using a 10x high-impedance probe. Do not use 50 ohm termination.
    * ADS-B pulses on baseband should appear when RF-IN is connected.
    * Adjust RV1 from minimum to maximum while observing.
    * Determine optimum RV1 setting.
    * Measure and record voltage at TP14 allowing RV1 to be removed, and R26/R27 voltage divider to be adjusted accordingly in next revision.
  * Differential signal
    * Connect probe grounds to board ground
    * Probe 10x CH1 on TP16
    * Probe 10x CH2 on TP17
    * Do not connect a probe ground clip to TP16 or TP17
    * Check TP16 and TP17 individually first. Each should sit near TP15, about 1.65V, and remain within the 0V to 3.3V ADC input range.
    * Enable math: CH1 - CH2. Math trace is the differential signal being driven toward the ADC.
    * Output should resemble ADS-B baseband pulses when a suitable 1090MHz signal is present.
    * This is what the ADC sees
* Remove power

### Third Power-Up

* FPGA attachment gates:
  * Confirm the FPGA board is Smart ZYNQ SL V1.2/V1.3.
  * Confirm FPGA bank 33 VCCO is 3.3V.
  * Confirm FPGA bank 35 VCCO is 3.3V.
  * Confirm the FPGA design sets ADC data and OTR pins as inputs or high impedance before the ADC can drive them.
  * Confirm the FPGA design drives ADC CLK.
  * Confirm GPS TX and PPS pins are FPGA inputs or high impedance.
  * Confirm GPS RX and GPS reset are driven by the FPGA.
  * Confirm the bench supply is disconnected from J4.
  * Confirm both boards are unpowered before mating.
  * Confirm the headers are aligned correctly before applying power.
* Attach to FPGA board.
* Power FPGA board.
* Stop immediately if the FPGA supply reports over-current, a rail is low, or anything heats unexpectedly.
* Multimeter checks: check voltages
  * Place black probe on pin 36 of connector J4 (GND)
  * Set to DC voltage
  * Place red probe on TP20, ensure 4.5V - 5V
  * Place red probe on TP11, ensure 3.3V
  * Place red probe on TP1, ensure 3.3V
  * Place red probe on TP14, ensure about 0.80V to 0.87V
  * Place red probe on TP15, ensure about 1.65V
  * Check TP21 with a DMM or 10x high-impedance probe only. Ensure about 1V.
  * Check U1 pin 6 pad, ensure 3.3V
* Remove power
* Detach from FPGA board.
* Fit GPS module.
* Attach GPS antenna.

### Fourth Power-Up

* Repeat the FPGA attachment gates from Third Power-Up.
* Attach to FPGA board.
* Power FPGA board.
* Stop immediately if the FPGA supply reports over-current, a rail is low, or anything heats unexpectedly.
* Multimeter checks: check voltages
  * Place black probe on pin 36 of connector J4 (GND)
  * Set to DC voltage
  * Place red probe on TP20, ensure 4.5V - 5V
  * Place red probe on TP11, ensure 3.3V
  * Place red probe on TP1, ensure 3.3V
  * Place red probe on TP14, ensure about 0.80V to 0.87V
  * Place red probe on TP15, ensure about 1.65V
  * Check TP21 with a DMM or 10x high-impedance probe only. Ensure about 1V.
  * Check GPS module pin 6, ensure 3.3V
* Confirm LED6 flashes at 1Hz, indicating PPS.
* Confirm FPGA can interface with ADC and GPS.
* Test RGB LEDs.

## Next steps if we get this far

* Celebrate
* Play with NanoVNA to tune RF section

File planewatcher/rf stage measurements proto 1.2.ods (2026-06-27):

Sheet: Pluto Output Calibration
Pluto TX Gain | Digital Scale | TinySA level after 50dB (dBm) | Inferred Pluto Output (dBm)
-10 dB | 0.5 | -46 | 4
-20 dB | 0.5 | -56 | -6
-30 dB | 0.5 | -66 | -16
-40 dB | 0.5 | -76 | -26
Pluto TX Gain | Digital scale | Measured (dB) | Relative change (dB) | Expected relative change
-20 dB | 1 | -70 | reference | reference
-20 dB | 0.5 | -76 | -6 | -6 dB amplitude power change
-20 dB | 0.25 | -82 | -12 | about -12dB
-20 dB | 0.125 | -88.1 | -18.1 | about -18dB

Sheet: NanoVNA S11
NanoVNA Center Freq | 1090MHz
NanoVNA Span | 80MHz
NanoVNA Port 1 Power | -10 dB
NanoVNA Bandwidth Per Hz | 1000
NanoVNA VF | 70.00%
NanoVNA Test | S11
Board | 0000 | 0001 | 0002 | 0003
DUT State: | Unpowered | Unpowered | Unpowered | Unpowered
S11 LogMag: | -23.1dB | -17.7 dB | -17.8dB | -17.6dB
S11 Smith | 56.5 ohms @ 41pF | 60.69 ohms @ 15pF | 60.4 ohms @ 14.9pF | 60.1 ohms @ 13.9pF
VSWR: | ~1.15:1 | ~1.30:1 | ~1.30:1 | ~1.30:1
Result: | PASS | PASS | PASS | PASS
DUT State: | Powered | Powered | Powered | Powered
S11 LogMag: | -17 dB | -18.1dB | -15.2 dB | -16.9dB
S11 Smith | 64.02 ohms @ 18.7pF | 63.8 ohms @ 53pF | 68.2 ohms @ 15pF | 65.4 ohms @ 24.7pF
VSWR: | ~1.33:1 | ~1.28:1 | ~1.42:1 | ~1.33:1
Result: | PASS | PASS | PASS | PASS

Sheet: NanoVNA S21 DO NOT TRUST
NanoVNA Centre Freq. |  | 1090MHz
Span: |  | 80MHz
Start freq. |  | 1050MHz
Stop freq. |  | 1130MHz
Port 1 power: |  | -10 dB
Probe attenuation |  | 6.7dB
Board |  | 0000 | 0001 | 0002 | 0003
State |  | Powered | Powered | Powered | Powered
RF IN connector (no 50dB atten.) | RF side of TVS, Shunt inductor, input of C32 | -15 dB | -8 dB | -11 dB | -5 dB
Input-side C32 (no 50dB atten.) | Same net above, on input pin of AC coupling cap to first LNA | -9 dB | -7 dB | -10.9 dB | -6.3 dB
Output-side C32 (no 50dB atten.) | Output in of AC coupling cap to first LNA, input of first LNA | -10 dB | -9.8 dB | -10.7 dB | -6.3 dB
Input-side C33 (with 50dB atten.) | Output of first LNA, on input of AC coupling cap | -45 dB | -45 dB | -46 dB | -44 dB
Output-side C33 (with 50dB atten.) | Output of AC coupling cap, input of first SAW filter | -45 dB | -45 dB | -46 dB | -44 dB
Input-side C38 (with 50dB atten.) | Input of AC coupling cap, output of first SAW filter | -47 dB | -45 dB | -49 dB | -48 dB
Output-side C38 (with 50dB atten.) | Output of AC coupling cap, input of second LNA | -47 dB | -43.1 dB | -49 dB | -48 dB
Input-side C39 (with 50dB atten.) | Input of AC coupling cap, output of second LNA | -37 dB | -30 dB | -36.1 dB | -33.7 dB
Output-side C39 (with 50dB atten.) | Output of AC coupling cap, input of second SAW filter | -37 dB | -32 dB | -35.8 dB | -33 dB
Input-side R43 (with 50dB atten.) | Input of 0 ohm link (unpopulated pi attenuator) | -38 dB | -34 dB | -40.1 dB | -38 dB
Output-side R43 (with 50dB atten.) | Output of 0 ohm link (unpopulated pi attenuator) | -38 dB | -32 dB | -38.4 dB | -35 dB
Input-side C42 (with 50dB atten.) | Input of AC coupling cap and 52.3 ohm resistor to ground | -36 dB | -34 dB | -37.4 dB | -34 dB
Output-side C42 (with 50dB atten.) | Output of AC coupling cap, input of ADL5513 log detector | -33 dB | -32.5 dB | -37.1 dB | -36 dB
Likely 1-2dB fudge factor at every measurement…
i am almost certain the measurement differences will be with out measurement set-up. we don't have a proper rf-grade probe, we have an SMA pigtail we cut in half and exposed the centre conductor as a "probe" with a short-ish ground wire to the shield.

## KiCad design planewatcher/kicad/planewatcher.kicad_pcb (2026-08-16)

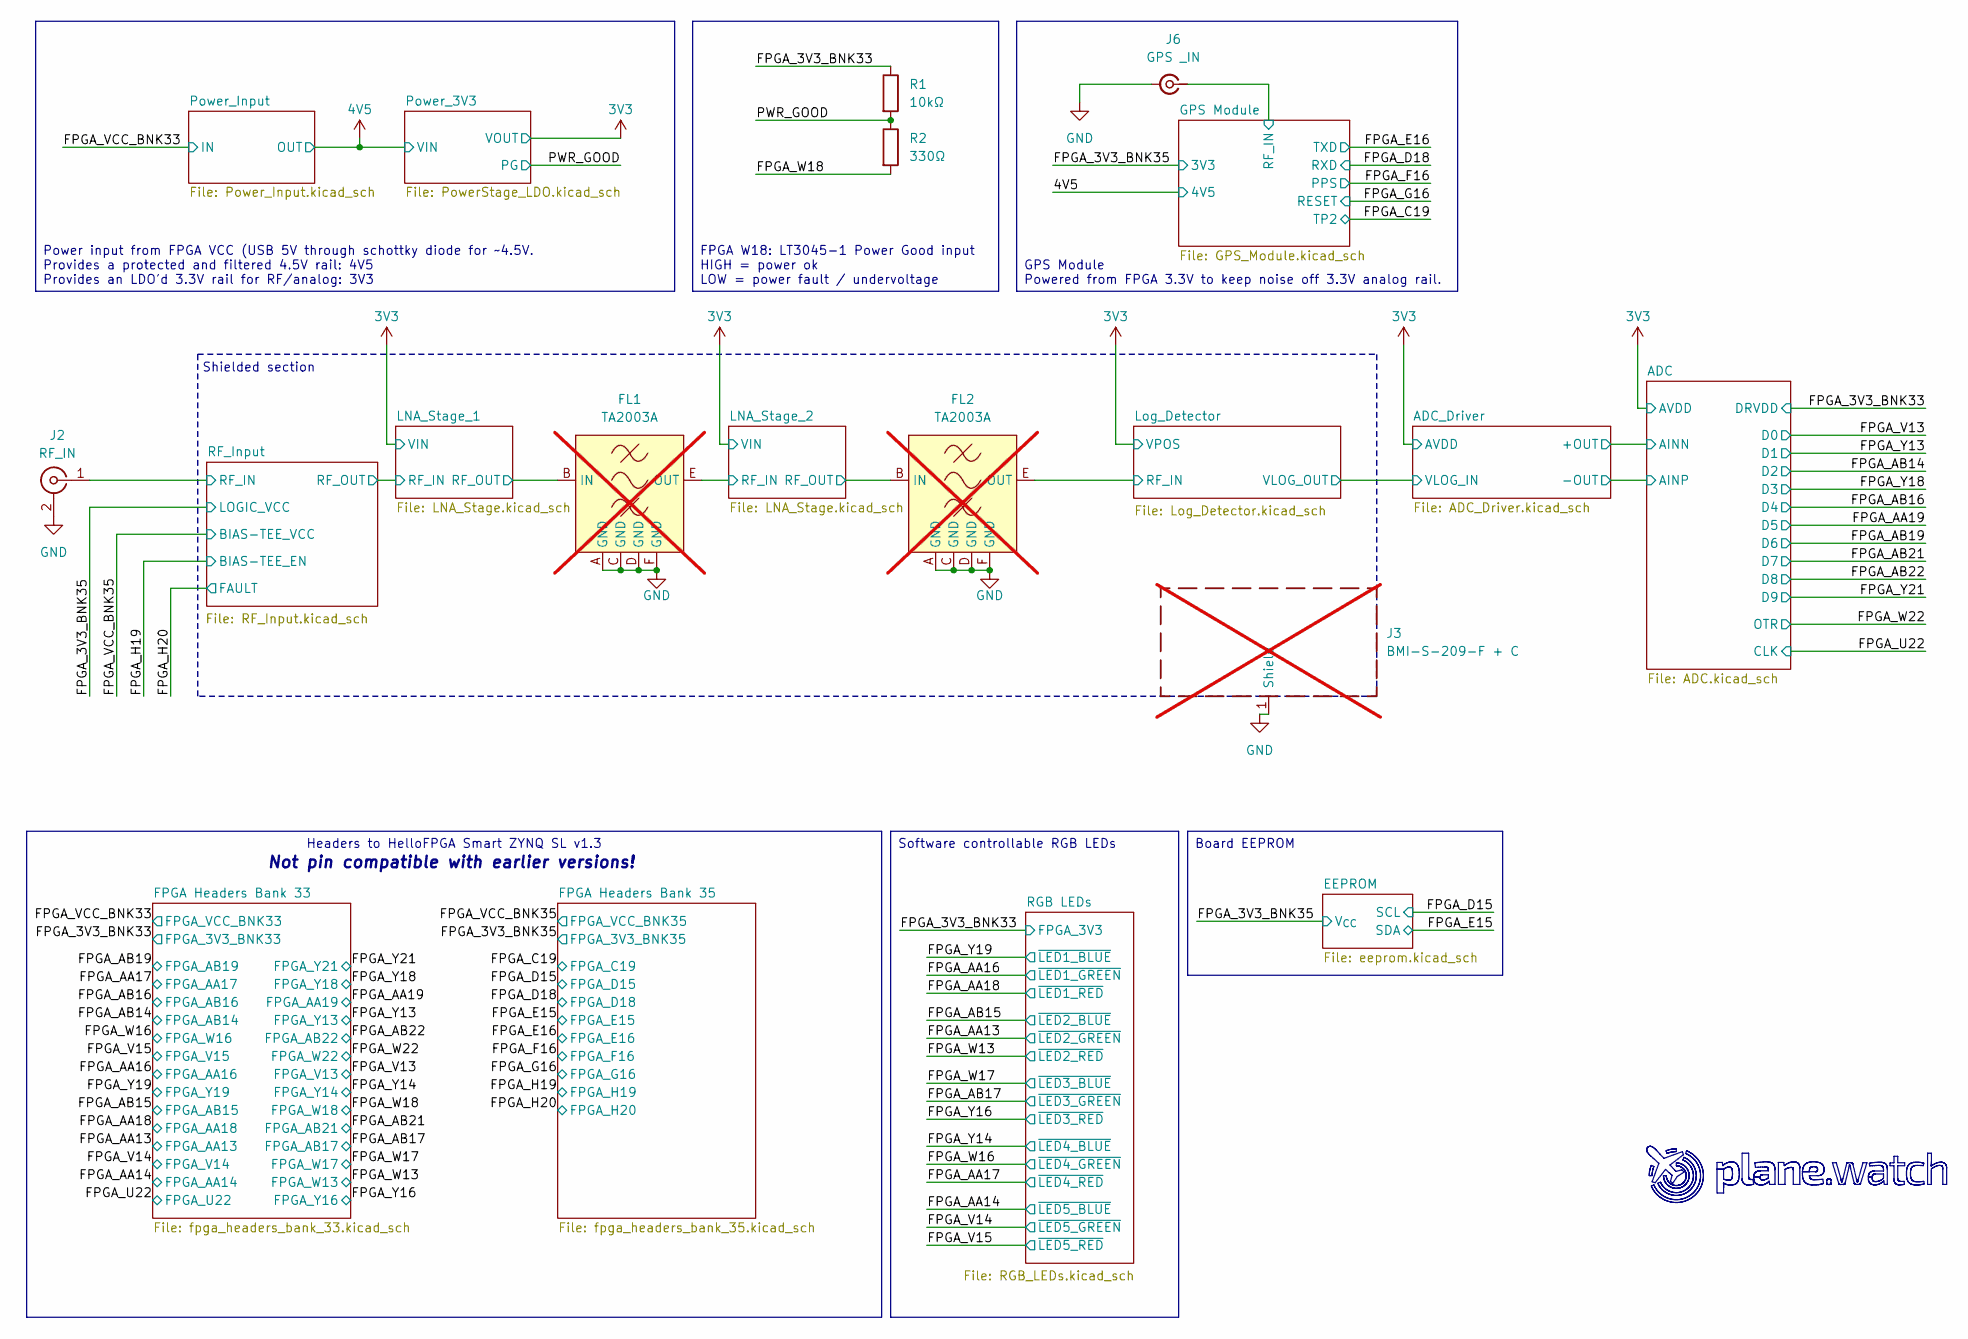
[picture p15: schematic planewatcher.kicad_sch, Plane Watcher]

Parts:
FL1, FL2: TA2003A; FL_Tai-Saw_TA2003A; MPN TA2003A; not fitted
J2: RF_IN; U.FL_Hirose_U.FL-R-SMT-1_Vertical; MPN U.FL-R-SMT-1; LCSC C88374
J3: BMI-S-209-F + C; Laird_Technologies_BMI-S-209-F_29.36x18.50mm; MPN BMI-S-209-F + BMI-S-209-C; not fitted
J6: GPS _IN; U.FL_Hirose_U.FL-R-SMT-1_Vertical; MPN U.FL-R-SMT-1; LCSC C88374
R1: 10kΩ; R_0402_1005Metric; MPN ERA-2AEB103X; LCSC C191915
R2: 330Ω; R_0402_1005Metric; MPN RT0402FRE07330RL; LCSC C854274

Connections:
/FPGA_3V3_BNK33: R1.1; also elsewhere on the board
/FPGA_W18: R2.2; also elsewhere on the board
/GPS Module/RF_IN: J6.1 (In); also elsewhere on the board
/LNA_Stage_1/RF_OUT: FL1.B (IN); also elsewhere on the board
/LNA_Stage_2/RF_IN: FL1.E (OUT); also elsewhere on the board
/LNA_Stage_2/RF_OUT: FL2.B (IN); also elsewhere on the board
/Log_Detector/RF_IN: FL2.E (OUT); also elsewhere on the board
/PWR_GOOD: R1.2, R2.1; also elsewhere on the board
/RF_Input/RF_IN: J2.1 (In); also elsewhere on the board
GND: FL1.A (GND), FL1.C (GND), FL1.D (GND), FL1.F (GND), FL2.A (GND), FL2.C (GND), FL2.D (GND), FL2.F (GND), J2.2 (Ext), J3.1 (Shield_1), J6.2 (Ext); also elsewhere on the board

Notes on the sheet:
Shielded section
Not pin compatible with earlier versions!
Board EEPROM
FPGA W18: LT3045-1 Power Good input HIGH = power ok LOW = power fault / undervoltage
Power input from FPGA VCC (USB 5V through schottky diode for ~4.5V. Provides a protected and filtered 4.5V rail: 4V5 Provides an LDO'd 3.3V rail for RF/analog: 3V3
GPS Module Powered from FPGA 3.3V to keep noise off 3.3V analog rail.
Headers to HelloFPGA Smart ZYNQ SL v1.3
Software controllable RGB LEDs

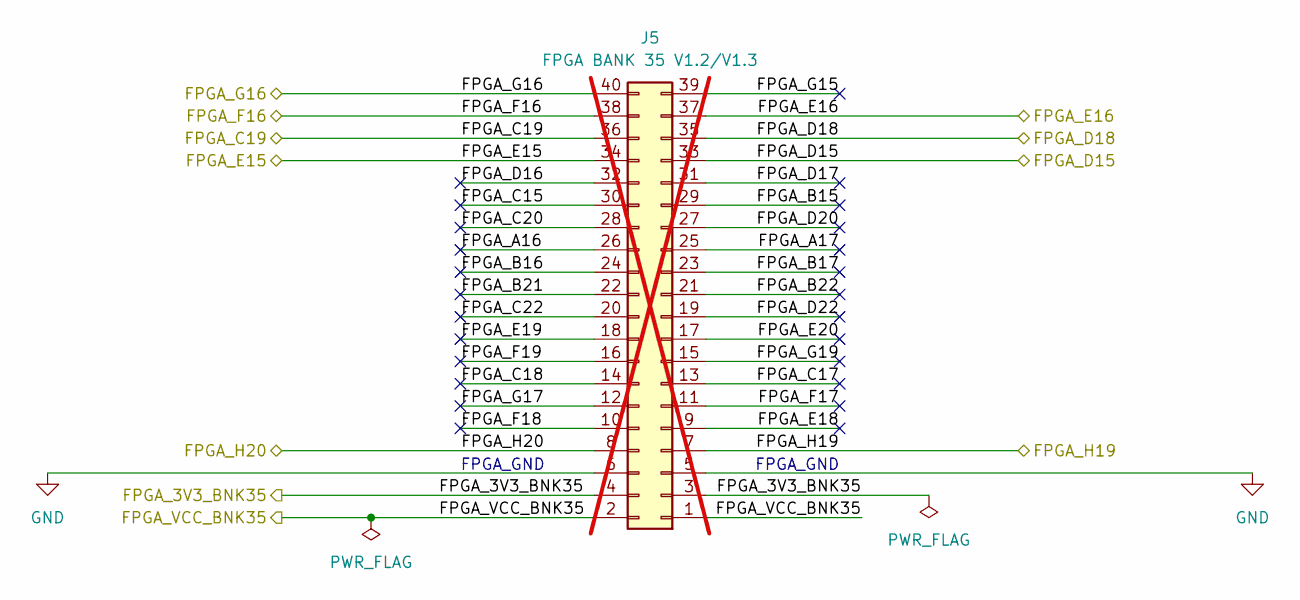
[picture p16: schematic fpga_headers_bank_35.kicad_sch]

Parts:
J5: FPGA BANK 35 V1.2/V1.3; PinHeader_2x20_P2.54mm_Vertical; MPN TSW-120-07-L-D; LCSC C5968215; not fitted

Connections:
/FPGA Headers Bank 35/FPGA_A16: J5.26
/FPGA Headers Bank 35/FPGA_A17: J5.25
/FPGA Headers Bank 35/FPGA_B15: J5.29
/FPGA Headers Bank 35/FPGA_B16: J5.24
/FPGA Headers Bank 35/FPGA_B17: J5.23
/FPGA Headers Bank 35/FPGA_B21: J5.22
/FPGA Headers Bank 35/FPGA_B22: J5.21
/FPGA Headers Bank 35/FPGA_C15: J5.30
/FPGA Headers Bank 35/FPGA_C17: J5.13
/FPGA Headers Bank 35/FPGA_C18: J5.14
/FPGA Headers Bank 35/FPGA_C20: J5.28
/FPGA Headers Bank 35/FPGA_C22: J5.20
/FPGA Headers Bank 35/FPGA_D16: J5.32
/FPGA Headers Bank 35/FPGA_D17: J5.31
/FPGA Headers Bank 35/FPGA_D20: J5.27
/FPGA Headers Bank 35/FPGA_D22: J5.19
/FPGA Headers Bank 35/FPGA_E18: J5.9
/FPGA Headers Bank 35/FPGA_E19: J5.18
/FPGA Headers Bank 35/FPGA_E20: J5.17
/FPGA Headers Bank 35/FPGA_F17: J5.11
/FPGA Headers Bank 35/FPGA_F18: J5.10
/FPGA Headers Bank 35/FPGA_F19: J5.16
/FPGA Headers Bank 35/FPGA_G15: J5.39
/FPGA Headers Bank 35/FPGA_G17: J5.12
/FPGA Headers Bank 35/FPGA_G19: J5.15
/FPGA_3V3_BNK35: J5.3, J5.4; also elsewhere on the board
/FPGA_C19: J5.36; also elsewhere on the board
/FPGA_D15: J5.33; also elsewhere on the board
/FPGA_D18: J5.35; also elsewhere on the board
/FPGA_E15: J5.34; also elsewhere on the board
/FPGA_E16: J5.37; also elsewhere on the board
/FPGA_F16: J5.38; also elsewhere on the board
/FPGA_G16: J5.40; also elsewhere on the board
/FPGA_H19: J5.7; also elsewhere on the board
/FPGA_H20: J5.8; also elsewhere on the board
/FPGA_VCC_BNK35: J5.1, J5.2; also elsewhere on the board
GND: J5.5, J5.6; also elsewhere on the board

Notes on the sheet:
FPGA_GND

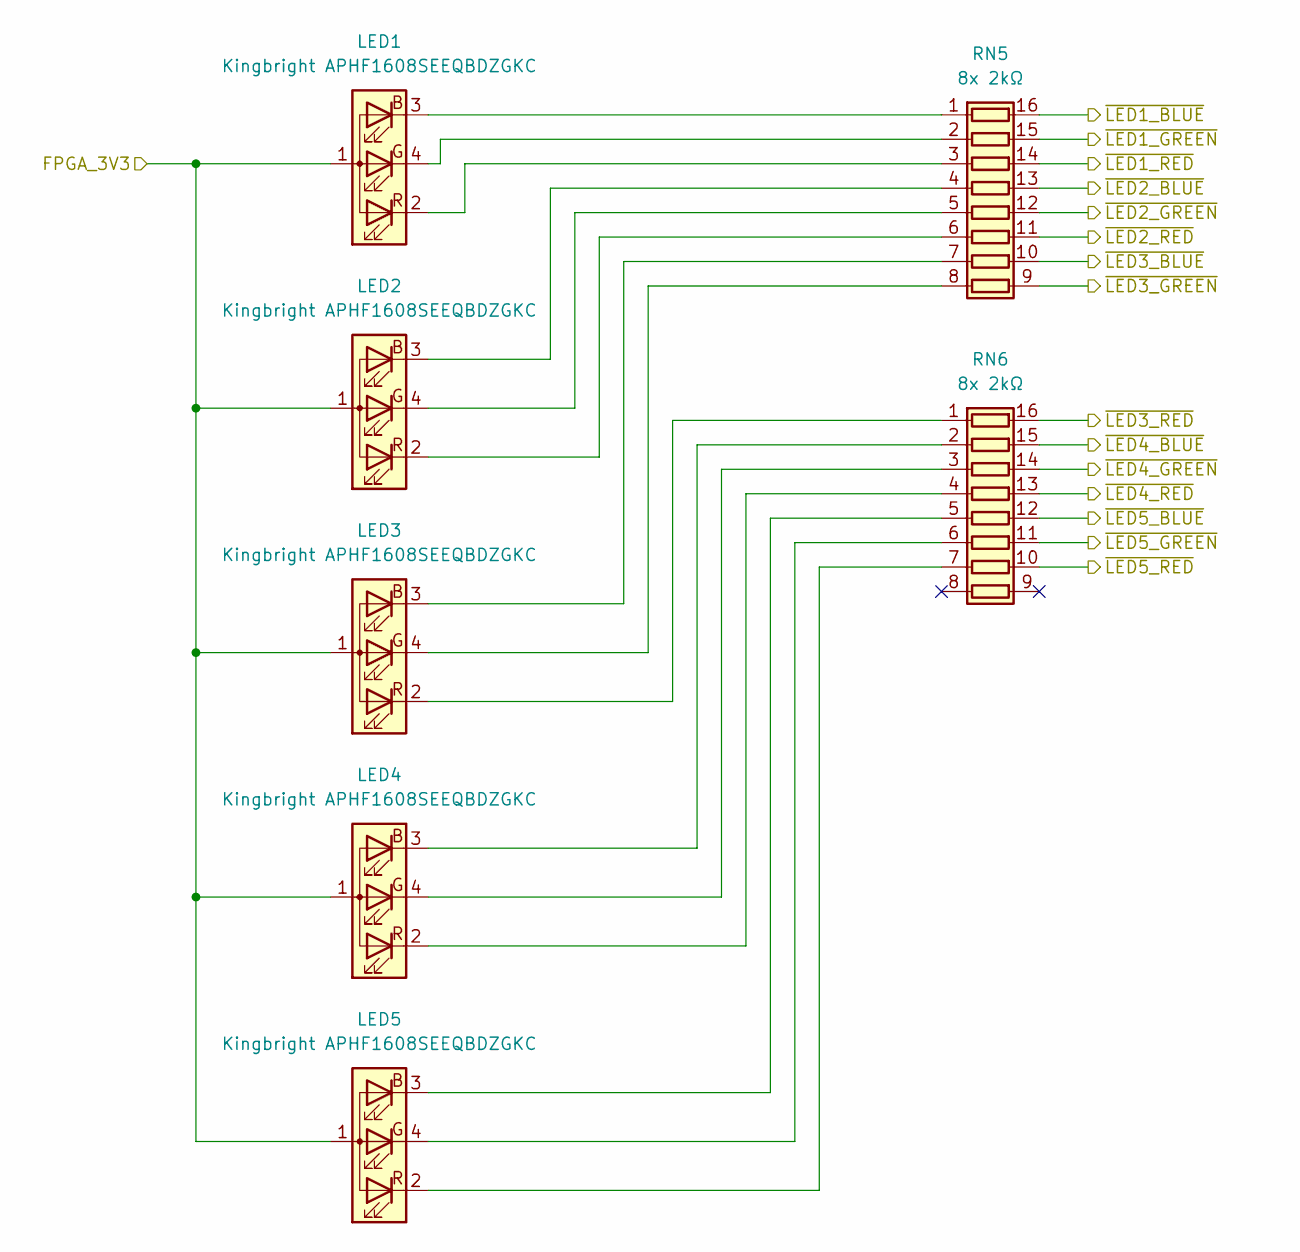
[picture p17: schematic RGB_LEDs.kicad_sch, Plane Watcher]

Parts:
LED1, LED2, LED3, LED4, LED5: Kingbright APHF1608SEEQBDZGKC; LED_Kingbright_APHF1608SEEQBDZGKC; MPN APHF1608SEEQBDZGKC; LCSC C5145179
RN5, RN6: 8x 2kΩ; 8x0402; MPN YC248-JR-072KL; LCSC C874618

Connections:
/FPGA_3V3_BNK33: LED1.1 (A), LED2.1 (A), LED3.1 (A), LED4.1 (A), LED5.1 (A); also elsewhere on the board
/FPGA_AA13: RN5.12 (R5.2); also elsewhere on the board
/FPGA_AA14: RN6.12 (R5.2); also elsewhere on the board
/FPGA_AA16: RN5.15 (R2.2); also elsewhere on the board
/FPGA_AA17: RN6.13 (R4.2); also elsewhere on the board
/FPGA_AA18: RN5.14 (R3.2); also elsewhere on the board
/FPGA_AB15: RN5.13 (R4.2); also elsewhere on the board
/FPGA_AB17: RN5.9 (R8.2); also elsewhere on the board
/FPGA_V14: RN6.11 (R6.2); also elsewhere on the board
/FPGA_V15: RN6.10 (R7.2); also elsewhere on the board
/FPGA_W13: RN5.11 (R6.2); also elsewhere on the board
/FPGA_W16: RN6.14 (R3.2); also elsewhere on the board
/FPGA_W17: RN5.10 (R7.2); also elsewhere on the board
/FPGA_Y14: RN6.15 (R2.2); also elsewhere on the board
/FPGA_Y16: RN6.16 (R1.2); also elsewhere on the board
/FPGA_Y19: RN5.16 (R1.2); also elsewhere on the board
unnamed: LED1.3 (BK), RN5.1 (R1.1)
unnamed: LED1.4 (GK), RN5.2 (R2.1)
unnamed: LED1.2 (RK), RN5.3 (R3.1)
unnamed: LED2.3 (BK), RN5.4 (R4.1)
unnamed: LED2.4 (GK), RN5.5 (R5.1)
unnamed: LED2.2 (RK), RN5.6 (R6.1)
unnamed: LED3.3 (BK), RN5.7 (R7.1)
unnamed: LED3.4 (GK), RN5.8 (R8.1)
unnamed: LED3.2 (RK), RN6.1 (R1.1)
unnamed: LED4.3 (BK), RN6.2 (R2.1)
unnamed: LED4.4 (GK), RN6.3 (R3.1)
unnamed: LED4.2 (RK), RN6.4 (R4.1)
unnamed: LED5.3 (BK), RN6.5 (R5.1)
unnamed: LED5.4 (GK), RN6.6 (R6.1)
unnamed: LED5.2 (RK), RN6.7 (R7.1)

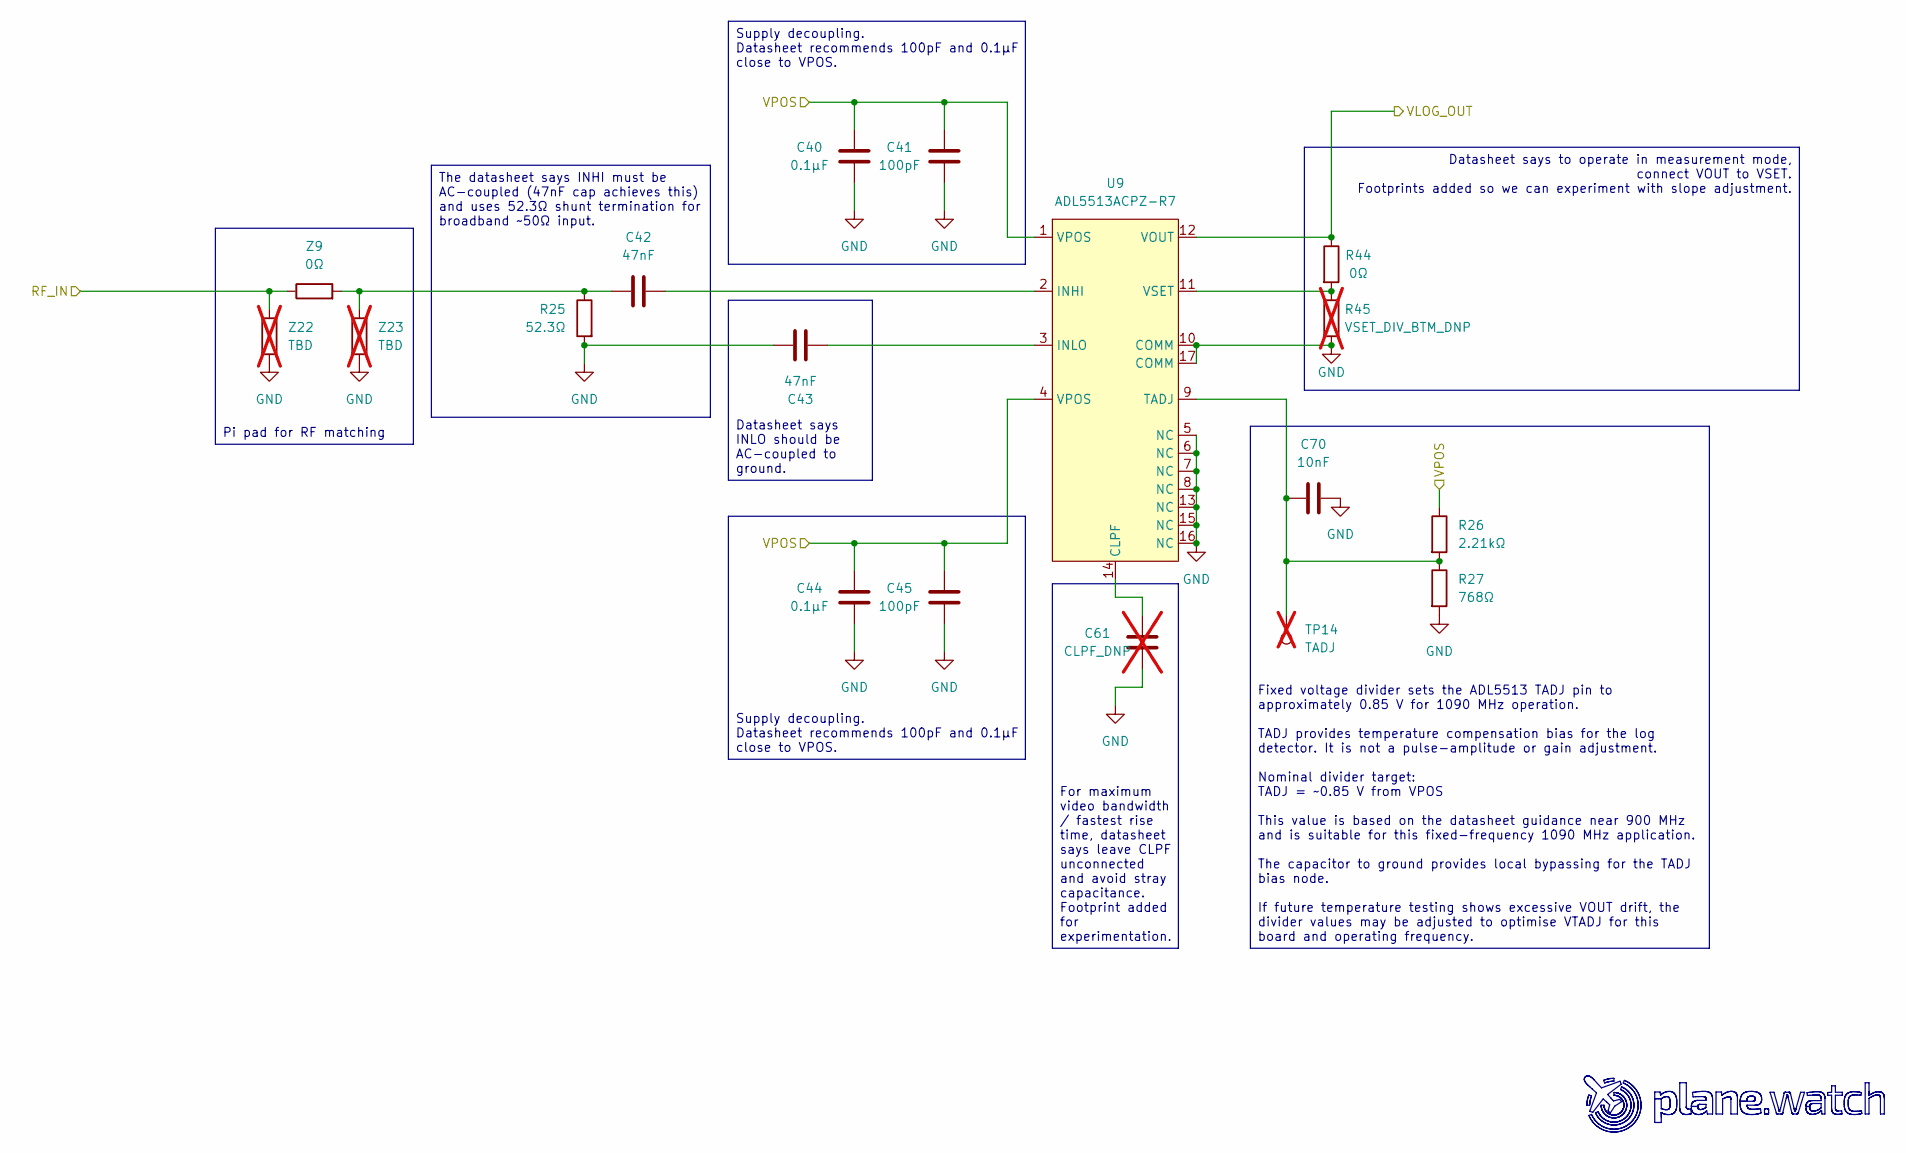
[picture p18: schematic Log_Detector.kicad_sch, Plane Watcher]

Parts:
C40, C44: 0.1µF; C_0402_1005Metric; MPN GCM155R71A104KA55D; LCSC C161163
C41, C45: 100pF; C_0402_1005Metric; MPN GCM1555C1H101FA16D; LCSC C2941926
C42, C43: 47nF; C_0402_1005Metric; MPN CC0402KRX7R6BB473; LCSC C327054
C61: CLPF_DNP; C_0402_1005Metric; MPN GCM1555C1H101FA16D; LCSC C2941926; not fitted
C70: 10nF; C_0402_1005Metric; MPN CL05B103KB5NNNC; LCSC C15195
R25: 52.3Ω; R_0402_1005Metric; MPN RC0402FR-0752R3L; LCSC C273696
R26: 2.21kΩ; R_0402_1005Metric; MPN ERJ2RKF2211X; LCSC C416496
R27: 768Ω; R_0402_1005Metric; MPN ERJ2RKF7680X; LCSC C3025660
R44: 0Ω; R_0402_1005Metric; MPN ERJ-2GE0R00X; LCSC C242160
R45: VSET_DIV_BTM_DNP; R_0402_1005Metric; not fitted
TP14: TADJ; TestPoint_THTPad_D1.0mm_Drill0.5mm; not fitted
U9: ADL5513ACPZ-R7; LFCSP-16-1EP_3x3mm_P0.5mm_EP1.6x1.6mm; MPN ADL5513ACPZ-R7; LCSC C579160
Z9: 0Ω; R_0402_1005Metric; MPN ERJ-2GE0R00X; LCSC C242160
Z22, Z23: TBD; R_0402_1005Metric; not fitted

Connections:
3V3: C40.2, C41.2, C44.2, C45.2, R26.1, U9.1 (VPOS), U9.4 (VPOS); also elsewhere on the board
/ADC_Driver/VLOG_IN: R44.1, U9.12 (VOUT); also elsewhere on the board
/Log_Detector/RF_IN: Z9.1, Z22.2; also elsewhere on the board
GND: C40.1, C41.1, C43.2, C44.1, C45.1, C61.1, C70.2, R25.2, R27.2, R45.2, U9.5 (NC), U9.6 (NC), U9.7 (NC), U9.8 (NC), U9.10 (COMM), U9.13 (NC), U9.15 (NC), U9.16 (NC), U9.17 (COMM), Z22.1, Z23.1; also elsewhere on the board
unnamed: C42.1, R25.1, Z9.2, Z23.2
unnamed: C61.2, U9.14 (CLPF)
unnamed: C42.2, U9.2 (INHI)
unnamed: C43.1, U9.3 (INLO)
unnamed: C70.1, R26.2, R27.1, TP14.1 (1_1), U9.9 (TADJ)
unnamed: R44.2, R45.1, U9.11 (VSET)

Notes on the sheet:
Supply decoupling. Datasheet recommends 100pF and 0.1µF close to VPOS.
The datasheet says INHI must be AC-coupled (47nF cap achieves this) and uses 52.3Ω shunt termination for broadband ~50Ω input.
Datasheet says to operate in measurement mode, connect VOUT to VSET. Footprints added so we can experiment with slope adjustment.
Datasheet says INLO should be AC-coupled to ground.
Fixed voltage divider sets the ADL5513 TADJ pin to approximately 0.85 V for 1090 MHz operation. TADJ provides temperature compensation bias for the log detector. It is not a pulse-amplitude or gain adjustment. Nominal divider target: TADJ = ~0.85 V from VPOS This value is based on the datasheet gui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
Pi pad for RF matching
For maximum video bandwidth / fastest rise time, datasheet says leave CLPF unconnected and avoid stray capacitance. Footprint added for experimentation.

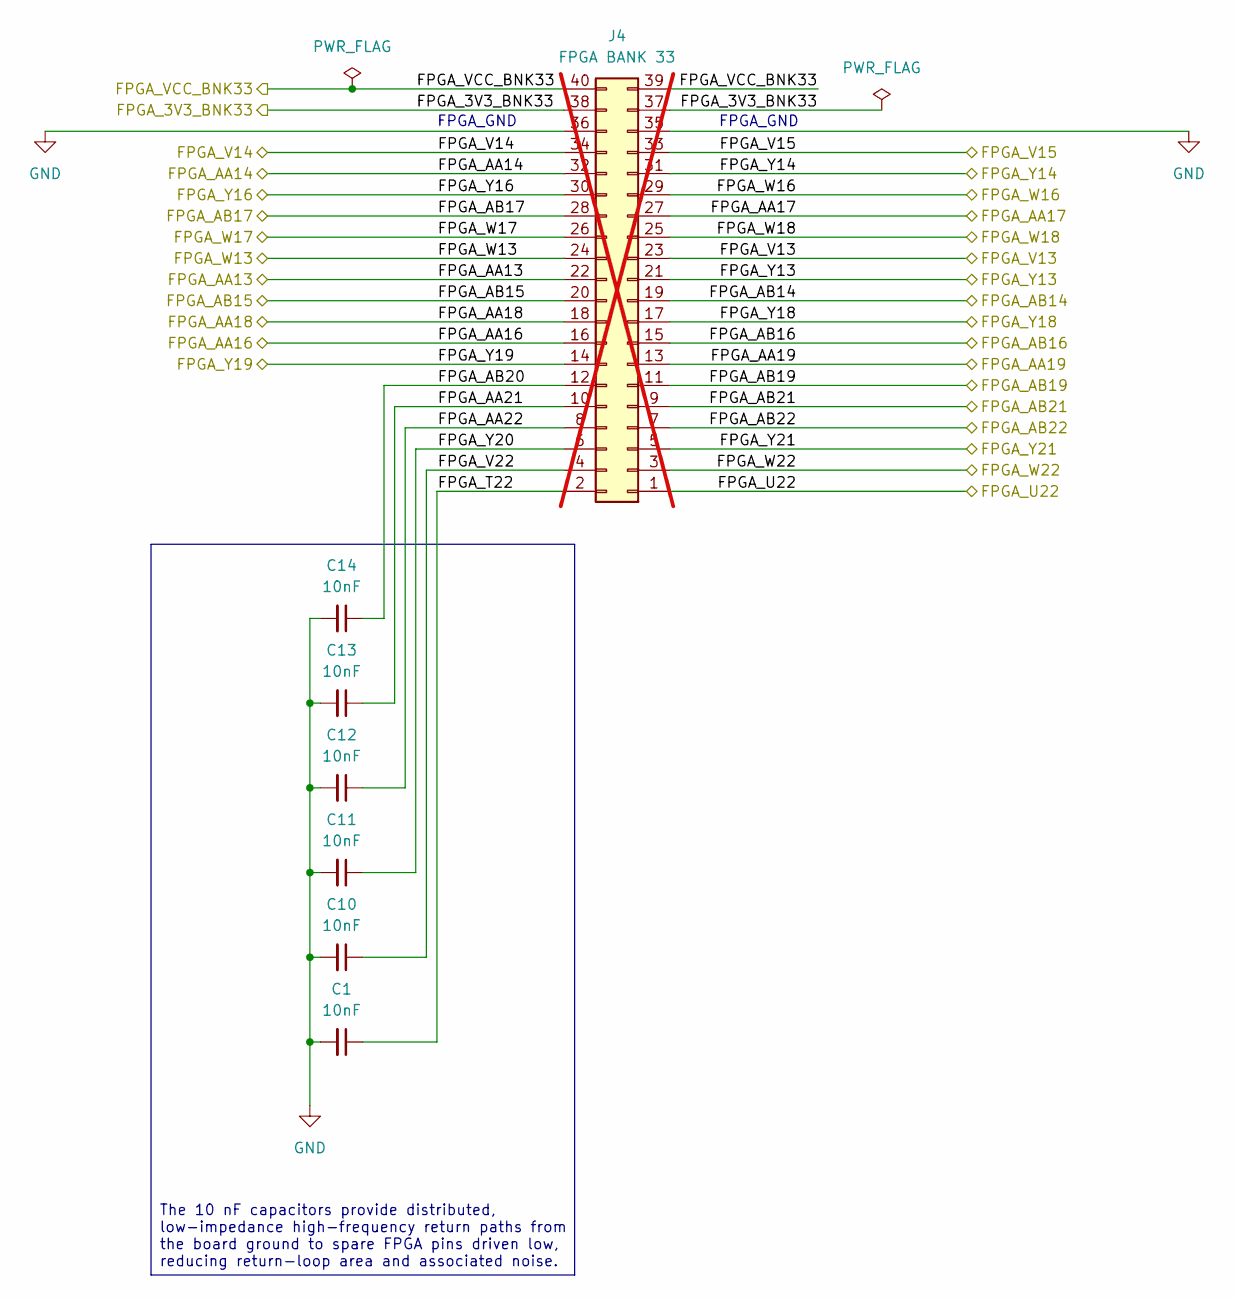
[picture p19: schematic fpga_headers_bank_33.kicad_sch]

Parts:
C1, C10, C13, C14: 10nF; C_0402_1005Metric; MPN GRM1555C1E103JE01D; LCSC C3855387
C11, C12: 10nF; C_0603_1608Metric; MPN GRM1885C1H103JA01D; LCSC C85973
J4: FPGA BANK 33; PinHeader_2x20_P2.54mm_Vertical; MPN TSW-120-07-L-D; LCSC C5968215; not fitted

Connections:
/FPGA Headers Bank 33/FPGA_AA21: C13.1, J4.10
/FPGA Headers Bank 33/FPGA_AA22: C12.1, J4.8
/FPGA Headers Bank 33/FPGA_AB20: C14.1, J4.12
/FPGA Headers Bank 33/FPGA_T22: C1.1, J4.2
/FPGA Headers Bank 33/FPGA_V22: C10.1, J4.4
/FPGA Headers Bank 33/FPGA_Y20: C11.1, J4.6
/FPGA_3V3_BNK33: J4.37, J4.38; also elsewhere on the board
/FPGA_AA13: J4.22; also elsewhere on the board
/FPGA_AA14: J4.32; also elsewhere on the board
/FPGA_AA16: J4.16; also elsewhere on the board
/FPGA_AA17: J4.27; also elsewhere on the board
/FPGA_AA18: J4.18; also elsewhere on the board
/FPGA_AA19: J4.13; also elsewhere on the board
/FPGA_AB14: J4.19; also elsewhere on the board
/FPGA_AB15: J4.20; also elsewhere on the board
/FPGA_AB16: J4.15; also elsewhere on the board
/FPGA_AB17: J4.28; also elsewhere on the board
/FPGA_AB19: J4.11; also elsewhere on the board
/FPGA_AB21: J4.9; also elsewhere on the board
/FPGA_AB22: J4.7; also elsewhere on the board
/FPGA_U22: J4.1; also elsewhere on the board
/FPGA_V13: J4.23; also elsewhere on the board
/FPGA_V14: J4.34; also elsewhere on the board
/FPGA_V15: J4.33; also elsewhere on the board
/FPGA_VCC_BNK33: J4.39, J4.40; also elsewhere on the board
/FPGA_W13: J4.24; also elsewhere on the board
/FPGA_W16: J4.29; also elsewhere on the board
/FPGA_W17: J4.26; also elsewhere on the board
/FPGA_W18: J4.25; also elsewhere on the board
/FPGA_W22: J4.3; also elsewhere on the board
/FPGA_Y13: J4.21; also elsewhere on the board
/FPGA_Y14: J4.31; also elsewhere on the board
/FPGA_Y16: J4.30; also elsewhere on the board
/FPGA_Y18: J4.17; also elsewhere on the board
/FPGA_Y19: J4.14; also elsewhere on the board
/FPGA_Y21: J4.5; also elsewhere on the board
GND: C1.2, C10.2, C11.2, C12.2, C13.2, C14.2, J4.35, J4.36; also elsewhere on the board

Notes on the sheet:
FPGA_GND
The 10 nF capacitors provide distributed, low-impedance high-frequency return paths from the board ground to spare FPGA pins driven low, reducing return-loop area and associated noise.

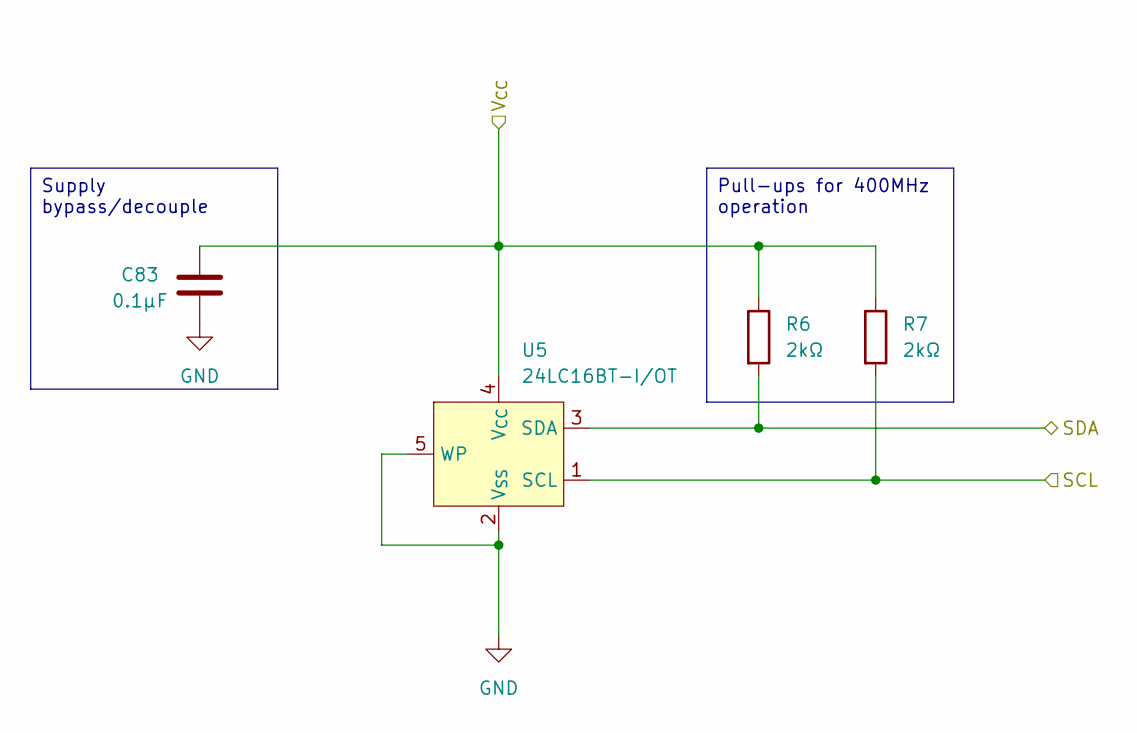
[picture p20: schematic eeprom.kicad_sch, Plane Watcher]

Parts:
C83: 0.1µF; C_0402_1005Metric; MPN GCM155R71A104KA55D; LCSC C161163
R6, R7: 2kΩ; R_0402_1005Metric; MPN ERJ2RKF2001X; LCSC C413086
U5: 24LC16BT-I/OT; SOT-23-5; MPN 24LC16BT-I/OT; LCSC C2061286

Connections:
/FPGA_3V3_BNK35: C83.1, R6.1, R7.1, U5.4 (V_{CC}); also elsewhere on the board
/FPGA_D15: R7.2, U5.1 (SCL); also elsewhere on the board
/FPGA_E15: R6.2, U5.3 (SDA); also elsewhere on the board
GND: C83.2, U5.2 (V_{SS}), U5.5 (WP); also elsewhere on the board

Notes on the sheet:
Pull-ups for 400MHz operation
Supply bypass/decouple

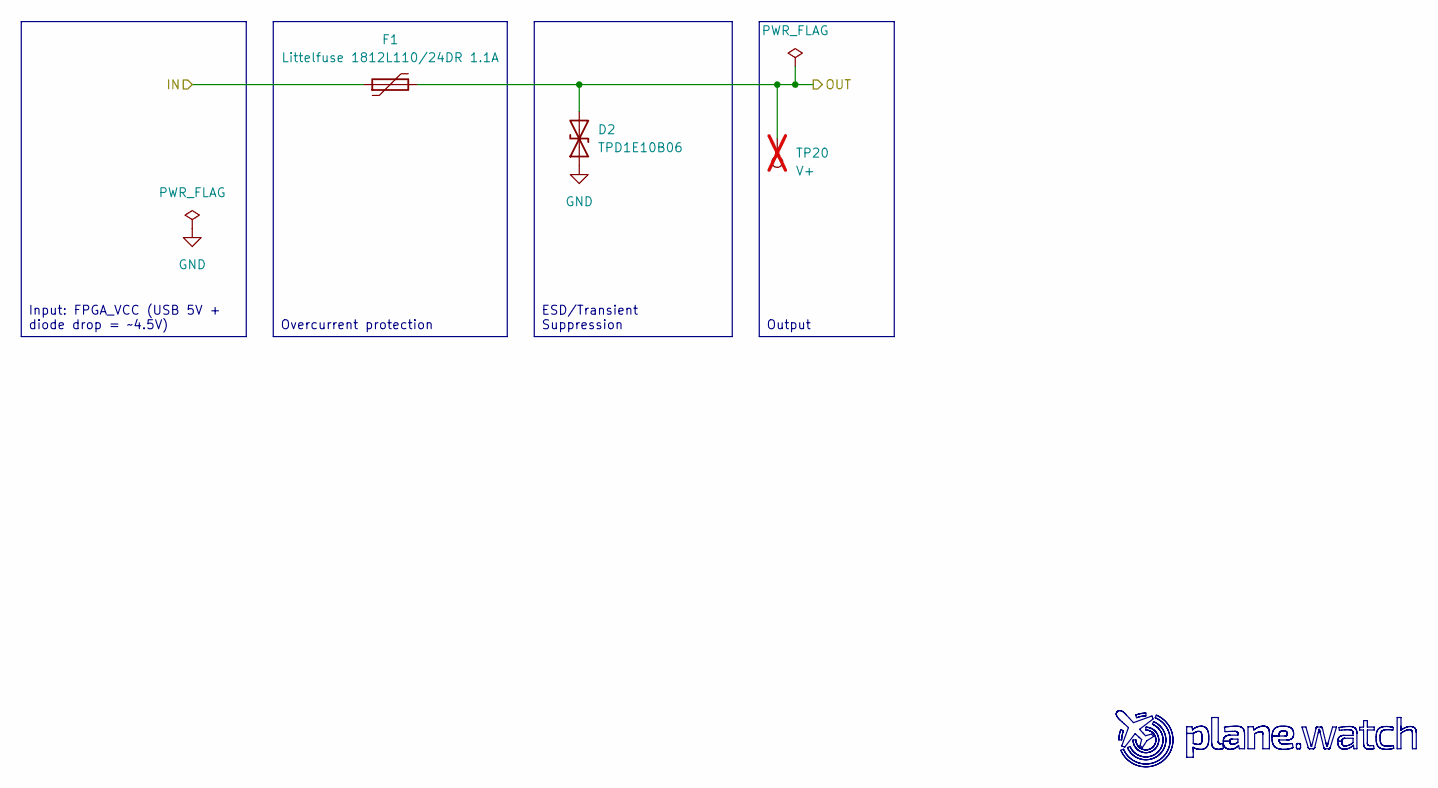
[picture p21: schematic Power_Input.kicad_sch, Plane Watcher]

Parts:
D2: TPD1E10B06; D_SOD-523; MPN TPD1E10B06DYAR; LCSC C3712135
F1: Littelfuse 1812L110/24DR 1.1A; Fuse_1812_4532Metric; MPN 1812L110/24DR; LCSC C207066
TP20: V+; TestPoint_THTPad_D1.0mm_Drill0.5mm; not fitted

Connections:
4V5: D2.2 (A2), F1.2, TP20.1 (1_1); also elsewhere on the board
/FPGA_VCC_BNK33: F1.1; also elsewhere on the board
GND: D2.1 (A1); also elsewhere on the board

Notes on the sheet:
Overcurrent protection
ESD/Transient Suppression
Input: FPGA_VCC (USB 5V + diode drop = ~4.5V)
Output

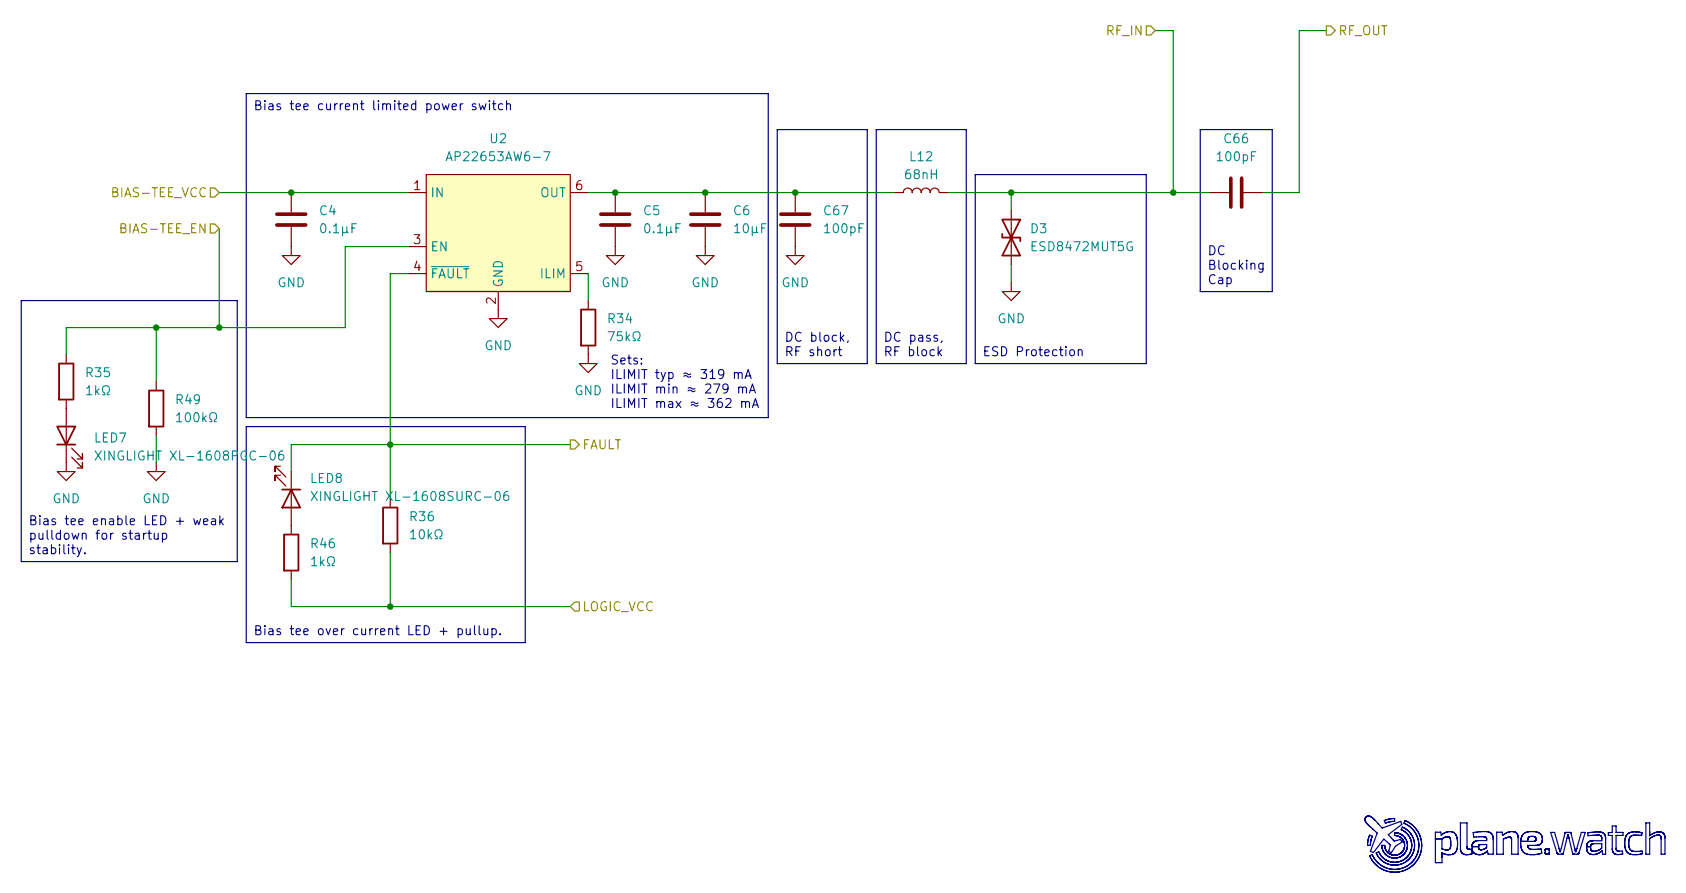
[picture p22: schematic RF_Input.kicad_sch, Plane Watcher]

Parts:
C4, C5: 0.1µF; C_0402_1005Metric; MPN GCM155R71A104KA55D; LCSC C161163
C6: 10µF; C_0603_1608Metric; MPN GRM188Z71A106MA73D; LCSC C237435
C66, C67: 100pF; C_0402_1005Metric; MPN GCM1555C1H101FA16D; LCSC C2941926
D3: ESD8472MUT5G; ESD8472; MPN ESD8472MUT5G; LCSC C133346
L12: 68nH; L_Coilcraft_0402DC_1005Metric; MPN 0402DC-68NXJRW; LCSC C3221883
LED7: XINGLIGHT XL-1608PGC-06; LED_0603_1608Metric; MPN XL-1608PGC-06; LCSC C7371905
LED8: XINGLIGHT XL-1608SURC-06; LED_0603_1608Metric; MPN XL-1608SURC-06; LCSC C965799
R34: 75kΩ; R_0402_1005Metric; MPN CRCW040275K0FKED; LCSC C482234
R35, R46: 1kΩ; R_0402_1005Metric; MPN RC0402FR-071KL; LCSC C106235
R36: 10kΩ; R_0402_1005Metric; MPN ERA-2AEB103X; LCSC C191915
R49: 100kΩ; R_0402_1005Metric; MPN CRCW0402100KFKED; LCSC C481918
U2: AP22653AW6-7; SOT26 (Type A1); MPN AP22653AW6-7; LCSC C1511768

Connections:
/FPGA_3V3_BNK35: R36.2, R46.2; also elsewhere on the board
/FPGA_H19: R35.1, R49.1, U2.3 (EN); also elsewhere on the board
/FPGA_H20: LED8.1 (K), R36.1, U2.4 (~FAULT); also elsewhere on the board
/FPGA_VCC_BNK35: C4.2, U2.1 (IN); also elsewhere on the board
/LNA_Stage_1/RF_IN: C66.1; also elsewhere on the board
/RF_Input/RF_IN: C66.2, D3.1 (A1), L12.2; also elsewhere on the board
GND: C4.1, C5.1, C6.1, C67.2, D3.2 (A2), LED7.1 (K), R34.2, R49.2, U2.2 (GND); also elsewhere on the board
unnamed: LED7.2 (A), R35.2
unnamed: LED8.2 (A), R46.1
unnamed: R34.1, U2.5 (ILIM)
unnamed: C5.2, C6.2, C67.1, L12.1, U2.6 (OUT)

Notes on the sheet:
Sets: ILIMIT typ ≈ 319 mA ILIMIT min ≈ 279 mA ILIMIT max ≈ 362 mA
Bias tee enable LED + weak pulldown for startup stability.
Bias tee current limited power switch
DC block, RF short
DC Blocking Cap
Bias tee over current LED + pullup.
DC pass, RF block
ESD Protection

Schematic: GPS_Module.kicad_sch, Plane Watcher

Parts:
C59: 10µF; C_0603_1608Metric; MPN GRM188Z71A106MA73D; LCSC C237435
C60, C62: 0.1µF; C_0402_1005Metric; MPN GCM155R71A104KA55D; LCSC C161163
C63: 4.7µF; C_0603_1608Metric; MPN GRM188Z71A475KE15D; LCSC C913474
C74: 10nF; C_0402_1005Metric; MPN CL05B103KB5NNNC; LCSC C15195
D4, D5: ESD8472MUT5G; ESD8472; MPN ESD8472MUT5G; LCSC C133346
J1: 1PPS_OUT; U.FL_Hirose_U.FL-R-SMT-1_Vertical; MPN U.FL-R-SMT-1; LCSC C88374
L10: 600Ω @ 100MHz; L_0805_2012Metric; MPN BLM21SP601SN1D; LCSC C3716677
LED6: XINGLIGHT XL-1608UPC-06; LED_0603_1608Metric; MPN XL-1608UPC-06; LCSC C2977076
R20: 10Ω; R_0402_1005Metric; MPN RE0402DRE0710RL; LCSC C4240446
R21, R23, R24: 33Ω; R_0402_1005Metric; MPN RC0402FR-0733RL; LCSC C138002
R32: 2.2kΩ; R_0402_1005Metric; MPN CRCW04022K20JNED; LCSC C4202009
R33: 49.9Ω 0.5W; R_0805_2012Metric; MPN ERJP06F49R9V; LCSC C77379
R47: 100kΩ; R_0402_1005Metric; MPN CRCW0402100KFKED; LCSC C481918
U1: LEA-M8T; ublox_LEA; MPN LEA-M8T; LCSC C2763452; not fitted
U4: TC4427; MSOP-8_3x3mm_P0.65mm; MPN TC4427EUA713; LCSC C628550

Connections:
4V5: C62.1, C63.1, U4.6 (V_{DD}); also elsewhere on the board
/FPGA_3V3_BNK35: L10.1; also elsewhere on the board
/FPGA_C19: U1.12 (TP2/~SAFEBOOT); also elsewhere on the board
/FPGA_D18: R24.1; also elsewhere on the board
/FPGA_E16: R23.1; also elsewhere on the board
/FPGA_F16: R21.2; also elsewhere on the board
/FPGA_G16: U1.10 (~RESET); also elsewhere on the board
/GPS Module/RF_IN: D4.1 (A1), U1.16 (RF_IN); also elsewhere on the board
GND: C59.2, C60.2, C62.2, C63.2, C74.2, D4.2 (A2), D5.2 (A2), J1.2 (Ext), R32.1, R47.2, U1.7 (GND), U1.13 (GND), U1.14 (GND), U1.15 (GND), U1.17 (GND), U1.24 (VDD_USB), U4.3 (GND); also elsewhere on the board
unnamed: D5.1 (A1), J1.1 (In), R33.2
unnamed: LED6.2 (A), U4.5 (OUT_B)
unnamed: LED6.1 (K), R32.2
unnamed: R24.2, U1.4 (RXD/SPI_MOSI)
unnamed: R21.1, R47.1, U1.28 (TIMEPULSE), U4.2 (IN_A), U4.4 (IN_B)
unnamed: R23.2, U1.3 (TXD/SPI_MISO)
unnamed: C59.1, C60.1, L10.2, U1.6 (VCC), U1.11 (V_BCKP)
unnamed: C74.1, R20.2, U1.18 (VCC_RF)
unnamed: R20.1, U1.19 (V_ANT)
unnamed: R33.1, U4.7 (OUT_A)

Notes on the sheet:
Series damping/termination for FPGA digital I/O
Bypass/decoupling for GPS supply. Ferrite bead ${/7a4a4324-e8b8-4d06-b75a-28095d4e9f10/84812100-48e5-47cc-a358-d48bbae76aaf/2e6ac265-d097-4125-9632-2b6c4976fe0c:REFERENCE} to suppress any high frequency noise back feeding into supply.
If the USB interface is not used, the VDD_USB pin must be connected to GND.
LEA-M8S module includes a built in antenna bias supply for nominal 3 V antennas enabled by linking the filtered VCC_RF supply output pin to the V_ANT antenna supply input pin with a 10 Ohm resistor in series. The module then controls the power supply to the antenna, applying power whenever the rece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
Small series resistor ${/7a4a4324-e8b8-4d06-b75a-28095d4e9f10/84812100-48e5-47cc-a358-d48bbae76aaf/54395c4f-8dde-4acf-ac1a-c77d9f0de467:REFERENCE} feeding FPGA PPS input. Provides edge damping and modest input protection for the FPGA GPIO path. Weak pulldown via ${/7a4a4324-e8b8-4d06-b75a-28095d4e9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
ESD/Transient suppression
Buffers the GPS TIMEPULSE signal and provides enough output current to drive the external 1PPS coax output. Channel A drives the coax connector. Channel B drives the PPS LED.

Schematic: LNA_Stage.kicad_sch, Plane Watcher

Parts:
C28: 1µF; C_0402_1005Metric; MPN GRM155Z71A105KE01D; LCSC C528974
C29: 0.1µF; C_0402_1005Metric; MPN GCM155R71A104KA55D; LCSC C161163
C30: 1nF; C_0402_1005Metric; MPN GCM1555C1H102FA16D; LCSC C126493
C31, C32, C33: 100pF; C_0402_1005Metric; MPN GCM1555C1H101FA16D; LCSC C2941926
L7: 68nH; L_0603_1608Metric; MPN 0603CS-68NXJLW; LCSC C19191685
U7: TQP3M9036; U_Qorvo_TQP3M9036-QFN; MPN TQP3M9036; LCSC C920261
Z8, Z12: 0Ω; R_0402_1005Metric; MPN ERJ-2GE0R00X; LCSC C242160
Z13, Z15, Z17, Z18: TBD; R_0402_1005Metric; not fitted

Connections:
3V3: C28.2, C29.1, C30.1, C31.2, L7.1; also elsewhere on the board
/LNA_Stage_1/RF_IN: Z8.1, Z13.2; also elsewhere on the board
/LNA_Stage_1/RF_OUT: Z12.2, Z18.2; also elsewhere on the board
GND: C28.1, C29.2, C30.2, C31.1, U7.1 (NC), U7.3 (NC), U7.4 (NC), U7.5 (NC), U7.6 (Shutdown), U7.8 (NC), U7.EP (GND), Z13.1, Z15.1, Z17.1, Z18.1; also elsewhere on the board
unnamed: C32.2, Z8.2, Z15.2
unnamed: C33.1, Z12.1, Z17.2
unnamed: C32.1, U7.2 (RF_In)
unnamed: C33.2, L7.2, U7.7 (RF_Out)

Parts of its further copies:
C34: 1µF; C_0402_1005Metric; MPN GRM155Z71A105KE01D; LCSC C528974
C35: 0.1µF; C_0402_1005Metric; MPN GCM155R71A104KA55D; LCSC C161163
C36: 1nF; C_0402_1005Metric; MPN GCM1555C1H102FA16D; LCSC C126493
C37, C38, C39: 100pF; C_0402_1005Metric; MPN GCM1555C1H101FA16D; LCSC C2941926
L8: 68nH; L_0603_1608Metric; MPN 0603CS-68NXJLW; LCSC C19191685
R9: 0Ω; R_0402_1005Metric; MPN ERJ-2GE0R00X; LCSC C242160
U8: TQP3M9036; U_Qorvo_TQP3M9036-QFN; MPN TQP3M9036; LCSC C920261
Z14, Z16, Z19, Z21: TBD; R_0402_1005Metric; not fitted
Z20: 0Ω; R_0402_1005Metric; MPN ERJ-2GE0R00X; LCSC C242160

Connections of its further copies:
3V3: C34.2, C35.1, C36.1, C37.2, L8.1; also elsewhere on the board
/LNA_Stage_2/RF_IN: R9.1, Z14.2; also elsewhere on the board
/LNA_Stage_2/RF_OUT: Z20.2, Z21.2; also elsewhere on the board
GND: C34.1, C35.2, C36.2, C37.1, U8.1 (NC), U8.3 (NC), U8.4 (NC), U8.5 (NC), U8.6 (Shutdown), U8.8 (NC), U8.EP (GND), Z14.1, Z16.1, Z19.1, Z21.1; also elsewhere on the board
unnamed: C38.2, R9.2, Z16.2
unnamed: C39.1, Z19.2, Z20.1
unnamed: C38.1, U8.2 (RF_In)
unnamed: C39.2, L8.2, U8.7 (RF_Out)

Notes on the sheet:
Pi pad for RF matching
RF_IN and RF_OUT are 50Ω controlled-impedance RF traces. Keep short. No stubs. Reference solid GND plane.

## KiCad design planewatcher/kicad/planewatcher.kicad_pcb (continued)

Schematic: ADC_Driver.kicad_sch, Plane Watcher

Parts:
C7, C8: CF_DNP; C_0402_1005Metric; not fitted
C9: 2.2µF; C_0805_2012Metric; MPN CL21B225KBYVPNE; LCSC C5362585
C46, C48, C65, C82: 0.1µF; C_0402_1005Metric; MPN GCM155R71A104KA55D; LCSC C161163
C47, C64, C80, C81: 10µF; C_0603_1608Metric; MPN GRM188Z71A106MA73D; LCSC C237435
C71, C72: 20pF; C_0402_1005Metric; MPN GJM1555C1H200FB01D; LCSC C913479; not fitted
C78: 100pF; C_0402_1005Metric; MPN GCM1555C1H101FA16D; LCSC C2941926
C79: 1nF; C_0402_1005Metric; MPN GCM1555C1H102FA16D; LCSC C126493
R3: R_BASE_GND_DNP; R_0402_1005Metric; MPN ERJ-2GE0R00X; LCSC C242160; not fitted
R28, R29: 10kΩ; R_0402_1005Metric; MPN ERA-2AEB103X; LCSC C191915
R30, R31: 49.9Ω; R_0402_1005Metric; MPN RT0402BRD0749R9L; LCSC C852809
R51: 1MΩ; R_0402_1005Metric; MPN ERJ2RKF1004X; LCSC C413126
RN1: 4x 499Ω 1%; R_Array_Convex_4x0402; MPN 4D02WGF4990TCE; LCSC C620896
TP2: Noise Floor; TestPoint_THTPad_D1.0mm_Drill0.5mm; not fitted
TP15: VOCM; TestPoint_THTPad_D1.0mm_Drill0.5mm; not fitted
U3: OPA320; SOT-23-5; MPN OPA320AIDBVR; LCSC C92494
U10: AD8138; SOIC-8_3.9x4.9mm_P1.27mm; MPN AD8138ARZ; LCSC C113762
U12: ADA4807-1; SOT-23-6; MPN ADA4807-1ARJZ; LCSC C2058411

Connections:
3V3: C47.1, C48.1, C64.1, C65.1, C81.1, C82.1, R28.1, U3.5 (V+), U10.3 (V+), U12.5 (~DISABLE), U12.6 (+V_{S}); also elsewhere on the board
/ADC/AINN: C72.1, R30.2; also elsewhere on the board
/ADC/AINP: C71.2, R31.2; also elsewhere on the board
/ADC_Driver/VLOG_IN: U12.3 (+IN); also elsewhere on the board
GND: C9.2, C46.2, C47.2, C48.2, C64.2, C65.2, C71.1, C72.2, C78.2, C79.1, C80.2, C81.2, C82.2, R3.2, R29.2, U3.2 (V-), U10.6 (V-), U12.2 (-V_{S}); also elsewhere on the board
unnamed: C7.1, RN1.1 (R1.1), RN1.7 (R2.2), U10.1 (-IN)
unnamed: RN1.8 (R1.2), U3.1 (OUT), U3.4 (-IN)
unnamed: C7.2, R30.1, RN1.2 (R2.1), U10.4 (+OUT)
unnamed: C8.2, R31.1, RN1.3 (R3.1), U10.5 (-OUT)
unnamed: C8.1, RN1.4 (R4.1), RN1.6 (R3.2), U10.8 (+IN)
unnamed: R51.2, RN1.5 (R4.2), U12.1 (VOUT), U12.4 (-IN)
unnamed: C9.1, R3.1, R51.1, TP2.1 (1_1), U3.3 (+IN)
unnamed: C46.1, C78.1, C79.2, C80.1, R28.2, R29.1, TP15.1 (1_1), U10.2 (VOCM)

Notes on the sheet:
Unity-gain buffer for low-pass filter output
AD8138 Gain/Feedback
Supply decoupling
Slow analog baseline / noise-floor LPF R51 and C9 form a first-order low-pass filter from the buffered log-detector output to the U3B baseline buffer. This is used for slow analog DC centering before the AD8138/AD9203 path. With R51 = 1M and C9 = 2.2uF: tau = R*C = 2.2 s fc = 1/(2*pi*R*C) = 0.072 H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
Unity-gain buffer for log detector output
Set common-mode voltage to 3V3/2 = 1.65V
Series output isolation/termination resistors between AD8138 output and AD9203 input; works with the shunt capacitors to tune ADC input filtering/settling.
VOCM decoupling/bypassing

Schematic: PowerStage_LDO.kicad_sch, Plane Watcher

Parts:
C2, C22: 0.1µF; C_0402_1005Metric; MPN GCM155R71A104KA55D; LCSC C161163
C3: 1nF; C_0402_1005Metric; MPN GCM1555C1H102FA16D; LCSC C126493
C19: 4.7µF; C_1206_3216Metric; MPN CL31B475KBHNNNE; LCSC C51205; not fitted
C21: 4.7µF; C_1206_3216Metric; MPN CL31B475KBHNNNE; LCSC C51205
C26: 4.7µF; C_0603_1608Metric; MPN GRM188Z71A475KE15D; LCSC C913474
C27: 22µF; C_1206_3216Metric; MPN CL31B226KPHNNNE; LCSC C87996
L5: 600Ω @ 100MHz; L_0805_2012Metric; MPN BLM21SP601SN1D; LCSC C3716677
R18: 10kΩ; R_0402_1005Metric; MPN ERA-2AEB103X; LCSC C191915
R19: 93.1kΩ; R_0402_1005Metric; MPN TNPW040293K1BEED; LCSC C2088785
R22: 33.2kΩ; R_0603_1608Metric; MPN RT0603BRB0733K2L; LCSC C860335
TP1: 3V3; TestPoint_THTPad_D1.0mm_Drill0.5mm; not fitted
U6: LT3045/LT3045-1; U_LT3045IMSE-1#PBF; MPN LT3045IMSE#TRPBF; LCSC C666587

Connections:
3V3: C2.1, C3.1, C27.1, R19.2, TP1.1 (1_1), U6.10 (OUTS), U6.11 (OUT), U6.12 (OUT); also elsewhere on the board
4V5: C19.1, L5.1; also elsewhere on the board
/PWR_GOOD: U6.5 (PG); also elsewhere on the board
GND: C2.2, C3.2, C19.2, C21.2, C22.2, C26.1, C27.2, R18.1, R22.1, U6.6 (ILIM), U6.9 (GND), U6.13 (GND); also elsewhere on the board
unnamed: C21.1, C22.1, L5.2, U6.1 (IN), U6.2 (IN), U6.4 (EN/UV)
unnamed: R18.2, R19.1, U6.7 (PGFB)
unnamed: C26.2, R22.2, U6.8 (SET)

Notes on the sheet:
${/7a4a4324-e8b8-4d06-b75a-28095d4e9f10/e02d84ed-6468-4290-a59c-50ded41c0aba/d0620f5f-b1cf-4df8-a6ae-ece97448600e:REFERENCE} marked DNP to adhere to USB capacitance limit (although FPGA board waaaaay exceeds the limit anyway...
Set VOUT to 3.32V
KiCad cannot infer power through inductors/beads/filter parts.
Attempt to suppress digital noise coming in from power supply.
PG asserts nominally at 3.09 V, guaranteed by 3.20 V.
OUTS kelvin connected to output bulk cap
HF transient suppression
Input bulk.

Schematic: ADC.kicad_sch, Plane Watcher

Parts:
C49, C52, C55, C58: 10µF; C_0603_1608Metric; MPN GRM188Z71A106MA73D; LCSC C237435
C50, C51, C53, C54, C56, C57: 0.1µF; C_0402_1005Metric; MPN GCM155R71A104KA55D; LCSC C161163
C68, C73, C77: 1nF; C_0402_1005Metric; MPN GCM1555C1H102FA16D; LCSC C126493
C69, C75, C76: 100pF; C_0402_1005Metric; MPN GCM1555C1H101FA16D; LCSC C2941926
L6, L9: 600Ω @ 100MHz; L_0805_2012Metric; MPN BLM21SP601SN1D; LCSC C3716677
R4: 0Ω; R_0402_1005Metric; MPN ERJ-2GE0R00X; LCSC C242160; not fitted
R5: 0Ω; R_0402_1005Metric; MPN ERJ-2GE0R00X; LCSC C242160
RN2, RN3, RN4: 4x 22Ω 1%; R_Cat16-4; MPN CAY16-22R0F4LF; LCSC C1734385
U11: AD9203ARUZ; TSSOP-28_4.4x9.7mm_P0.65mm; MPN AD9203ARUZ; LCSC C653239

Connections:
3V3: L9.2; also elsewhere on the board
/ADC/ADC_AVDD: C51.1, C52.1, C73.2, C75.1, L9.1, U11.21 (PWRCON), U11.28 (AVDD)
/ADC/ADC_DRVDD: C49.1, C50.1, C68.2, C69.1, L6.2, U11.2 (DRVDD)
/ADC/AINN: U11.26 (AINN); also elsewhere on the board
/ADC/AINP: U11.25 (AINP); also elsewhere on the board
/FPGA_3V3_BNK33: L6.1; also elsewhere on the board
/FPGA_AA19: RN3.2 (R2.1); also elsewhere on the board
/FPGA_AB14: RN2.3 (R3.1); also elsewhere on the board
/FPGA_AB16: RN3.1 (R1.1); also elsewhere on the board
/FPGA_AB19: RN3.3 (R3.1); also elsewhere on the board
/FPGA_AB21: RN3.4 (R4.1); also elsewhere on the board
/FPGA_AB22: RN4.3 (R3.1); also elsewhere on the board
/FPGA_U22: RN4.4 (R4.1); also elsewhere on the board
/FPGA_V13: RN2.1 (R1.1); also elsewhere on the board
/FPGA_W22: RN4.1 (R1.1); also elsewhere on the board
/FPGA_Y13: RN2.2 (R2.1); also elsewhere on the board
/FPGA_Y18: RN2.4 (R4.1); also elsewhere on the board
/FPGA_Y21: RN4.2 (R2.1); also elsewhere on the board
GND: C49.2, C50.2, C51.2, C52.2, C53.2, C56.2, C57.2, C58.2, C68.1, C69.2, C73.1, C75.2, C76.2, C77.1, R5.2, U11.1 (DRVSS), U11.14 (DFS), U11.16 (3-STATE), U11.17 (STBY), U11.19 (CLAMP), U11.20 (CLAMPIN), U11.27 (AVSS); also elsewhere on the board
unnamed: RN2.8 (R1.2), U11.3 (D0)
unnamed: RN2.7 (R2.2), U11.4 (D1)
unnamed: RN2.6 (R3.2), U11.5 (D2)
unnamed: RN2.5 (R4.2), U11.6 (D3)
unnamed: RN3.8 (R1.2), U11.7 (D4)
unnamed: RN3.7 (R2.2), U11.8 (D5)
unnamed: RN3.6 (R3.2), U11.9 (D6)
unnamed: RN3.5 (R4.2), U11.10 (D7)
unnamed: RN4.8 (R1.2), U11.13 (OTR)
unnamed: RN4.7 (R2.2), U11.12 (D9)
unnamed: RN4.6 (R3.2), U11.11 (D8)
unnamed: RN4.5 (R4.2), U11.15 (CLK)
unnamed: C53.1, C54.1, C55.1, U11.24 (REFBF)
unnamed: R4.1, R5.1, U11.18 (REFSENSE)
unnamed: C54.2, C55.2, C56.1, U11.22 (REFTF)
unnamed: C57.1, C58.1, C76.1, C77.2, R4.2, U11.23 (VREF)

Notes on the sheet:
Series damping/termination for FPGA digital I/O
Bypass/decoupling for digital supply. Ferrite bead ${/7a4a4324-e8b8-4d06-b75a-28095d4e9f10/f77ae351-26f3-42d4-beb0-b884b17c3798/533e3aea-0b01-471e-8965-b1a7ec8870ac:REFERENCE} to suppress any high frequency noise entering digital supply.
Bypass/decoupling for analog supply. Ferrite bead ${/7a4a4324-e8b8-4d06-b75a-28095d4e9f10/f77ae351-26f3-42d4-beb0-b884b17c3798/90bf33f2-24fe-4a1e-9477-6f6210e09237:REFERENCE} to suppress any high frequency noise entering quiet analog supply.
VREF decoupling
Top and Bottom Reference Decoupling (as-per datasheet)
Ability to change 1Vp-p to 2Vp-p. 2Vp-p as-per schematic with ${/7a4a4324-e8b8-4d06-b75a-28095d4e9f10/f77ae351-26f3-42d4-beb0-b884b17c3798/c2c460cc-af40-46f2-a17d-a1fcea9bb573:REFERENCE} DNP and ${/7a4a4324-e8b8-4d06-b75a-28095d4e9f10/f77ae351-26f3-42d4-beb0-b884b17c3798/ce9a091b-3b33-4179-8729-958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

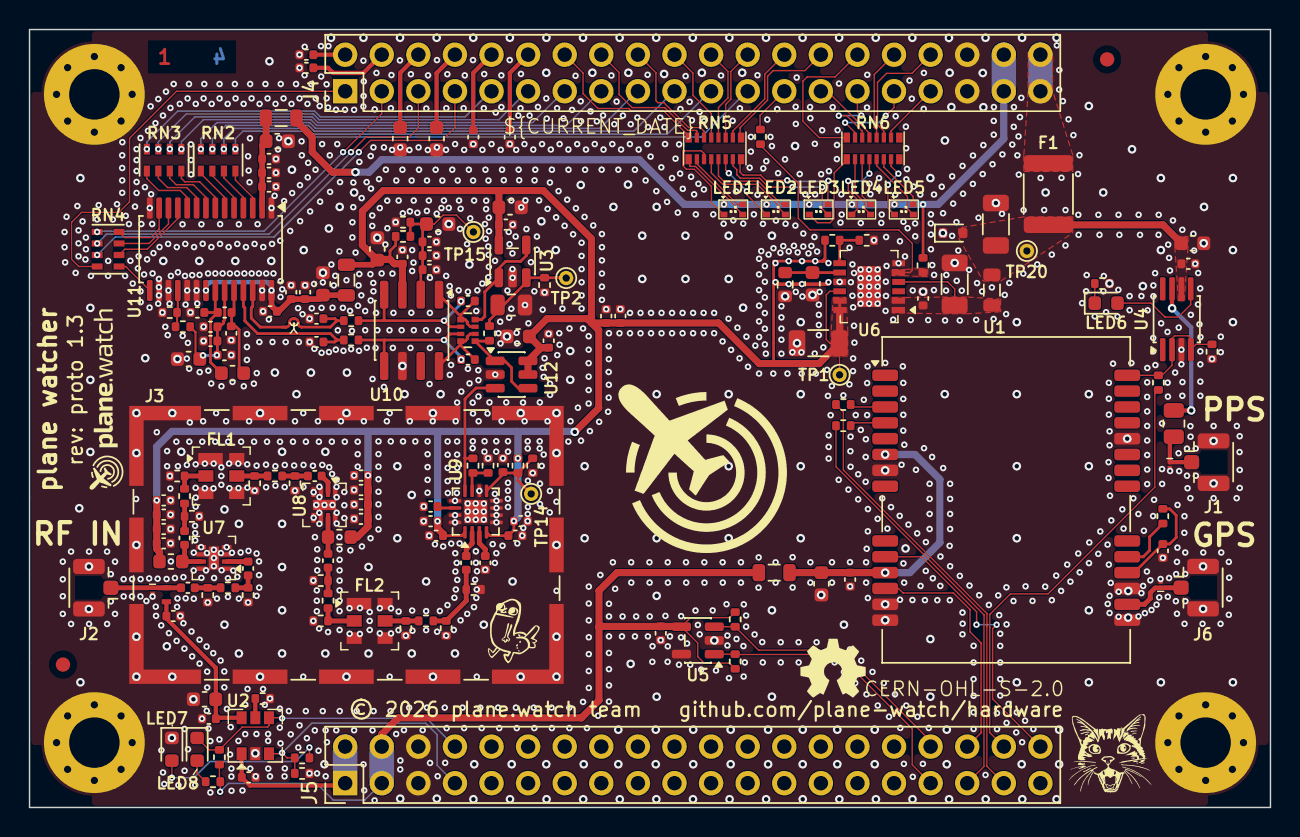
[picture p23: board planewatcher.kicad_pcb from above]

Board: 4 copper layers, 86.1 x 54.0 mm, 179 parts (0 on the bottom side), 133 nets.

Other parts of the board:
FID2, FID3: Fiducial_1mm_Mask2mm
MH1, MH2, MH3, MH4: MountingHole_3.5mm_Pad_Via

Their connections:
GND: MH1.1, MH2.1, MH3.1, MH4.1; also elsewhere on the board

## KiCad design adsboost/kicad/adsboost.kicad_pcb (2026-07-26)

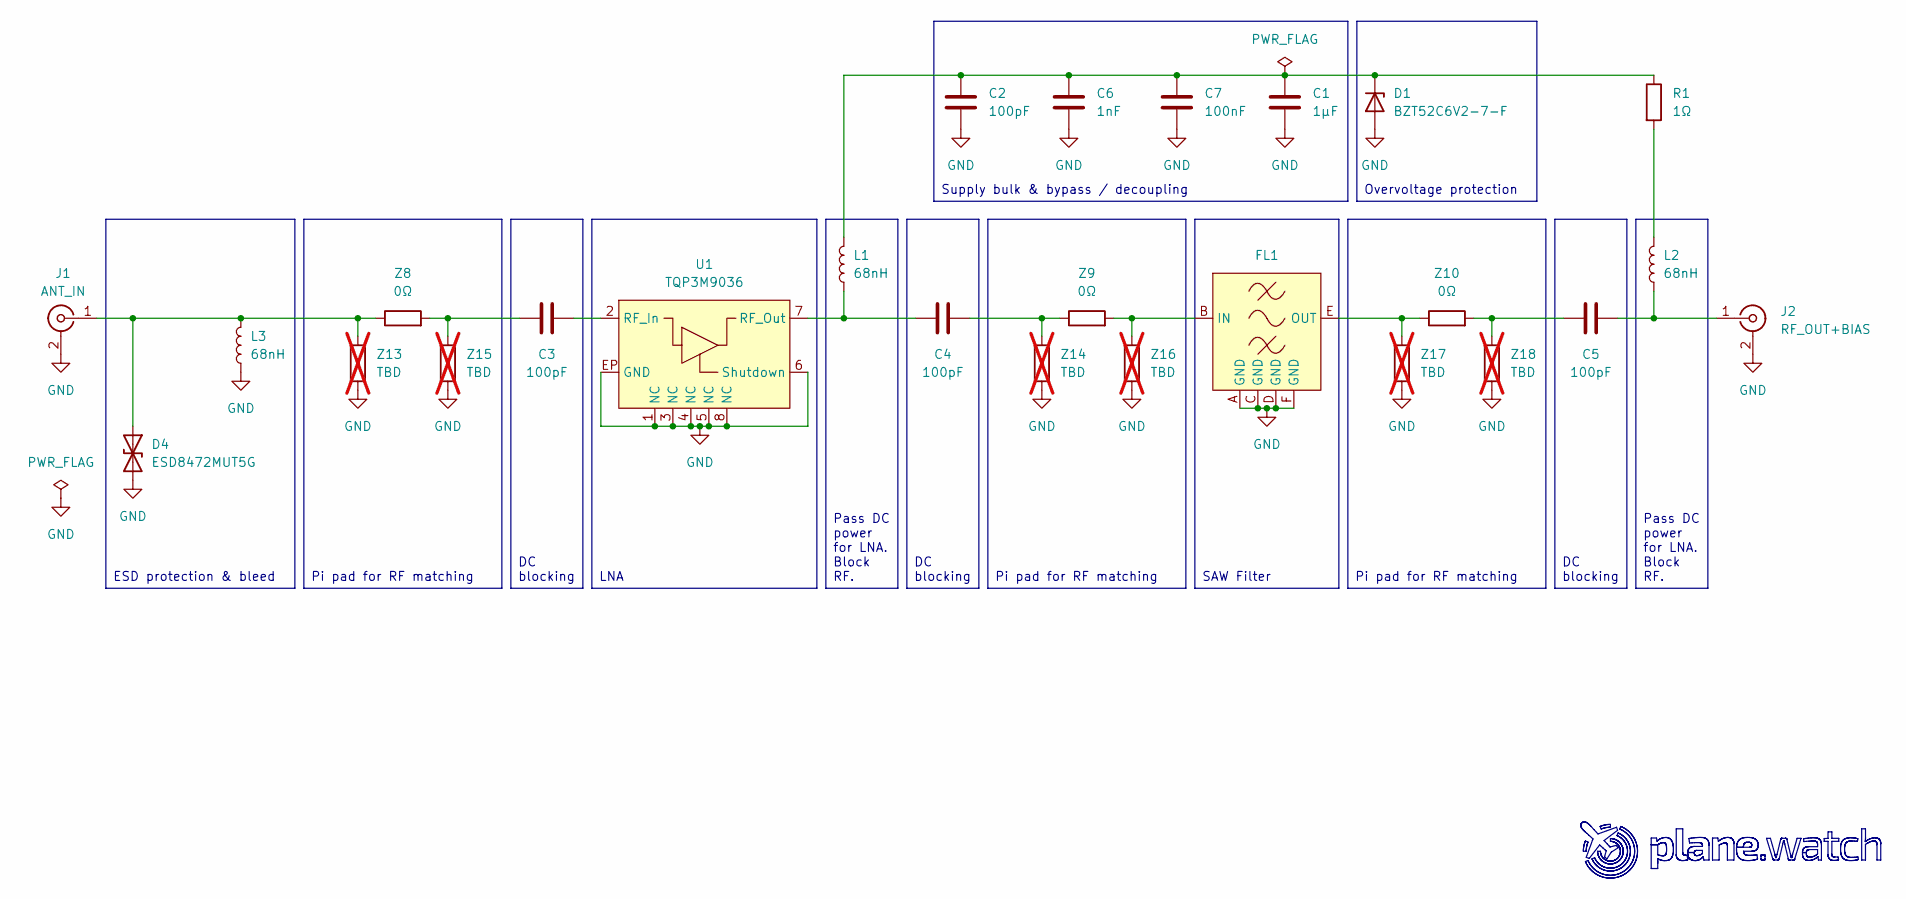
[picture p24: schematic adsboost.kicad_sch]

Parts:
C1: 1µF; C_0603_1608Metric; lcsc_id C85862
C2, C3, C4, C5: 100pF; C_0402_1005Metric; lcsc_id C2941926
C6: 1nF; C_0402_1005Metric; lcsc_id C126493
C7: 100nF; C_0402_1005Metric; lcsc_id C161163
D1: BZT52C6V2-7-F; D_SOD-123; lcsc_id C397931
D4: ESD8472MUT5G; ESD8472; MPN ESD8472MUT5G; lcsc_id C133346
FL1: TA2003A; FL_Tai-Saw_TA2003A
J1: ANT_IN; Amphenol 132289; lcsc_id C3172723
J2: RF_OUT+BIAS; Amphenol 132289; lcsc_id C3172723
L1, L2, L3: 68nH; L_Coilcraft_0402DC_1005Metric; MPN 0402DC-68NXJRW; lcsc_id C3221883
R1: 1Ω; R_0805_2012Metric; lcsc_id C313850
U1: TQP3M9036; U_Qorvo_TQP3M9036-QFN; lcsc_id C920261
Z8, Z9, Z10: 0Ω; R_0402_1005Metric; MPN ERJ-2GE0R00X; lcsc_id C242160
Z13, Z14, Z15, Z16, Z17, Z18: TBD; R_0402_1005Metric; not fitted

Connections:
GND: C1.2, C2.2, C6.2, C7.2, D1.2 (A), D4.2 (A2), FL1.A (GND), FL1.C (GND), FL1.D (GND), FL1.F (GND), J1.2 (Ext), J2.2 (Ext), L3.1, U1.1 (NC), U1.3 (NC), U1.4 (NC), U1.5 (NC), U1.6 (Shutdown), U1.8 (NC), U1.EP (GND), Z13.1, Z14.1, Z15.1, Z16.1, Z17.1, Z18.1
unnamed: C3.2, Z8.2, Z15.2
unnamed: C4.1, Z9.1, Z14.2
unnamed: C5.2, Z10.2, Z18.2
unnamed: C1.1, C2.1, C6.1, C7.1, D1.1 (K), L1.2, R1.1
unnamed: D4.1 (A1), J1.1 (In), L3.2, Z8.1, Z13.2
unnamed: FL1.B (IN), Z9.2, Z16.2
unnamed: FL1.E (OUT), Z10.1, Z17.2
unnamed: C5.1, J2.1 (In), L2.1
unnamed: L2.2, R1.2
unnamed: C3.1, U1.2 (RF_In)
unnamed: C4.2, L1.1, U1.7 (RF_Out)

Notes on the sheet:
Pi pad for RF matching
LNA
Overvoltage protection
Supply bulk & bypass / decoupling
DC blocking
ESD protection & bleed
Pass DC power for LNA. Block RF.
SAW Filter

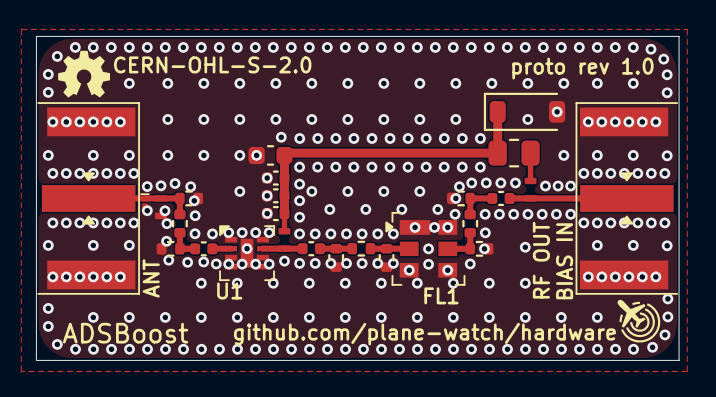
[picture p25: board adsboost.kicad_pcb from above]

Board: 4 copper layers, 35.7 x 18.0 mm, 26 parts (0 on the bottom side), 12 nets.

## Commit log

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2026-05-02 FPGA Power, FPGA data headers & series R, clean up
    [planewatcher.kicad_sch]
2026-05-03 fix errors
    - fix text in LT8640 symbol
    - fix missing net name on ADC input driver tage
    [planewatcher.kicad_sch]
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2026-05-08 swap ADC to AD9003 + schematic updates
    [ADC.kicad_sch, ADC_Driver.kicad_sch, LNA_Stage.kicad_sch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]
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2026-05-11 add jumpers for testing different power rails & additional test point
    [Log_Detector.kicad_sch, Power_Input.kicad_sch, planewatcher.kicad_pcb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]
2026-05-11 address & fix ERC errors/warnings
    [Log_Detector.kicad_sch, PowerStage_Buck.kicad_sch, PowerStage_Buck_LDO.kicad_sch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]
2026-05-11 fix all ERC & DRCC errors & warnings
    [ADC.kicad_sch, ADC_Driver.kicad_sch, Log_Detector.kicad_sch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]
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2026-05-13 fix via positioning
    [planewatcher.kicad_pcb]
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2026-05-13 mark RF shield as do not populate for prototype
    [planewatcher.kicad_pcb, planewatcher.kicad_sch]
2026-05-13 change AD8138 feedback resistor network in-line with datasheet
    [ADC_Driver.kicad_sch, planewatcher.kicad_pcb]
2026-05-15 rationalise power to single 3V3 rail fed from FPGA VCC
    [Log_Detector.kicad_sch, PowerStage_Buck.kicad_sch, PowerStage_Buck_LDO.kicad_sch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]
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2026-05-16 make AD8318 +OUT/-OUT test pads symmetric and minimal
    now as close to the pins as possible while maintaining clearances and guarded with via fencing
    [planewatcher.kicad_pcb]
2026-05-16 adjust silkscreen to ensure no overlap & adhere to clearances
    [planewatcher.kicad_pcb]
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2026-05-16 more vias because i have a mental problem
    [planewatcher.kicad_pcb]
2026-05-16 fix R43 metadata
    [Log_Detector.kicad_sch, planewatcher.kicad_pcb]
2026-05-16 update corner keep-out zones to only include fills
    [planewatcher.kicad_pcb]
2026-05-16 Add LDO PG pin to FPGA for monitoring in SW. Add Blinkenlights.
    [PowerStage_LDO.kicad_sch, RGB_LED.kicad_sch, bi_colour_led.kicad_sch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]
2026-05-16 Add voltage divider to PGFB to assert PG if 3V3 > ~3.1V. Fix length of AINN net.
    [PowerStage_LDO.kicad_sch, planewatcher.kicad_pcb]
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2026-05-16 Add persistent PCBWay BOM fields to KiCad schematic
    [ADC.kicad_sch, ADC_Driver.kicad_sch, LNA_Stage.kicad_sch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]
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2026-05-17 resolve "Missing symbol field 'Package' in footprint" DRC errors
    [planewatcher.kicad_pcb]
2026-05-17 replace manual layer markers with footprint
    [planewatcher.kicad_pcb]
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2026-05-18 fix incorrect part number
    [ADC.kicad_sch, planewatcher.kicad_pcb]
2026-05-18 fix LED order
    [planewatcher.kicad_sch]
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2026-05-19 swap TVS diodes with easier to source part
    [GPS_Module.kicad_sch, RF_Input_Protection.kicad_sch, planewatcher.kicad_pcb]
2026-05-19 add license & copyright info to schematic and pcb. fix layer window.
    [ADC.kicad_sch, ADC_Driver.kicad_sch, GPS_Module.kicad_sch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]
2026-05-19 DRC fixes
    [planewatcher.kicad_pcb]
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2026-05-20 update stackup for "JLC04161H-7628" and adjust impedance controlled traces
    [planewatcher.kicad_pcb]
2026-05-20 fix wrong date on silk
    [planewatcher.kicad_pcb]
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2026-05-20 add pink led for gps pps + attach gps reset to fpga
    [GPS_Module.kicad_sch, planewatcher.kicad_pcb, planewatcher.kicad_sch]
2026-05-20 fix drc by syncing fields
    [planewatcher.kicad_pcb]
2026-05-20 add missing 3D model
    [planewatcher.kicad_pcb]
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2026-05-20 correct 3d model for LT3045
    [planewatcher.kicad_pcb]
2026-05-20 update mask colour in line with what's been ordered
    [planewatcher.kicad_pcb]
2026-06-17 Change ADC gain/feedback network resistors to higher value
    - We were overloading the output of the ADL5513, with gain/feedback resistors with resistance too low.
    - Change R37, R38, R39 and R40 values from 499Ω to 4.7kΩ
    [ADC_Driver.kicad_sch]
2026-06-17 Add footprints for ADL5513 slope adjustment and output filtering
    - Add R44 (0Ω) & R45 (DNP, footprint only), allowing for replacement to adjust slope.
    - Add C61 (DNP, footprint only), allowing for output filtering to reduce output bandwidth if needed.
    [Log_Detector.kicad_sch, planewatcher.kicad_pcb]
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2026-06-18 Add bias-tee power switch & connect GPS TP2
    [GPS_Module.kicad_sch, RF_Input.kicad_sch, planewatcher.kicad_sch]
2026-06-18 Update PCB from schematic & bump version to proto 1.3
    [ADC.kicad_sch, ADC_Driver.kicad_sch, GPS_Module.kicad_sch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]
2026-06-18 Decrease brightness of PPS LED
    Bump up series resistor to 1kΩ from 58Ω (lol)
    [GPS_Module.kicad_sch]
2026-06-19 Swap the SMA connectors for U.FL
    [ADC.kicad_sch, ADC_Driver.kicad_sch, GPS_Module.kicad_sch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]
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2026-06-21 Add footprints for ADC driver feedback capacitors
    Cf in datasheet, figure 42.
    [ADC_Driver.kicad_sch, planewatcher.kicad_pcb]
2026-06-21 Implement log detector output buffering & buffered low-pass filter for noise offset
    - Implement low-pass filter to output noise floor with no pulses
    - Feed noise floor into ADC driver -IN to improve range/sensitivity
    - Buffer low pass filter output
    - Buffer log detector output with spare op amp in OPA2320 package
    - Tidy schematic & vias
    [ADC.kicad_sch, ADC_Driver.kicad_sch, planewatcher.kicad_pcb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]
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2026-06-22 Move U.FL connectors in as far as possible
    [planewatcher.kicad_pcb]
2026-06-22 Replace TADJ prototype trimmer with voltage divider
    Voltage divider sets the ADL5513 TADJ pin to approximately 0.85 V for 1090 MHz operation
    [ADC.kicad_sch, ADC_Driver.kicad_sch, GPS_Module.kicad_sch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]
2026-06-22 Mark impedance controlled traces as "RF_50Ω" in schematic
    [GPS_Module.kicad_sch, LNA_Stage.kicad_sch, Log_Detector.kicad_sch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]
2026-06-22 Update impedance controlled trace width following feedback from JLCPCB
    net class "RF_50Ω" now 0.34544mm trace width.
    [ADC.kicad_sch, ADC_Driver.kicad_sch, GPS_Module.kicad_sch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]
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2026-06-29 Replace AD8138 gain/feedback resistors with resistor array
    R37, R38, R39, R40 -> RN1.
    Resolves: https://github.com/plane-watch/hardware/pull/5#issuecomment-4815513095
    [ADC.kicad_sch, ADC_Driver.kicad_sch, GPS_Module.kicad_sch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]
2026-06-29 Add optional 2-section input LC matching/filter network
    Default: series 0R, shunts DNP.
    Populate after VNA/S11 testing to compensate ESD/bias-tee/LNA input parasitics.
    [ADC_Driver.kicad_sch, RF_Input.kicad_sch, planewatcher.kicad_pcb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]
2026-06-29 Add RF frontend tuning footprints
    Add DNP RF tuning footprints around the input match, SAW filter ports, and
    log detector input path. Update schematic annotations for VNA-populated C/L/R
    matching options, mark AD8138 feedback caps as optional, and update the PCB
    layout for the new RF frontend tuning network.
    [ADC_Driver.kicad_sch, Log_Detector.kicad_sch, RF_Input.kicad_sch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]
2026-06-29 Change all test point footprints to TestPoint_THTPad_D1.0mm_Drill0.5mm
    Had to move TP15 slightly to prevent it shorting to 3V3.
    [ADC.kicad_sch, ADC_Driver.kicad_sch, Log_Detector.kicad_sch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]
2026-06-29 Update LED series resistors with resistor arrays
    Also remove thermal vias - Shorty has a board heater now :)
    [RGB_LED.kicad_sch, RGB_LEDs.kicad_sch, planewatcher.kicad_pcb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]
2026-06-29 Update land pattern for ESD diodes to match mfr datasheet
    [ADC_Driver.kicad_sch, GPS_Module.kicad_sch, RF_Input.kicad_sch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]
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2026-06-29 Update purpose fields with more descriptive text for future me
    [ADC_Driver.kicad_sch, GPS_Module.kicad_sch, LNA_Stage.kicad_sch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]
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2026-06-29 Update issue date on drawings
    [ADC.kicad_sch, ADC_Driver.kicad_sch, GPS_Module.kicad_sch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]
2026-06-30 Slow down the LPF to avoid artificially raising the noise-floor baseline in high traffic areas
    [ADC_Driver.kicad_sch, planewatcher.kicad_pcb]
2026-06-30 Add RF short to ground on bias-tee supply
    [ADC.kicad_sch, ADC_Driver.kicad_sch, GPS_Module.kicad_sch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]
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2026-06-30 Tighten up RF section layout
    [planewatcher.kicad_pcb]
2026-07-03 Improve ADC reference and VOCM decoupling
    - Add extra RF bypassing on AD9203 supply/reference nodes
    - Add 100pF, 1nF, and 10uF bypassing on AD8138 VOCM
    - Reroute ADC-area traces in an attempt to reduce clock coupling into sensitive nodes
    [ADC.kicad_sch, ADC_Driver.kicad_sch, planewatcher.kicad_pcb]
2026-07-03 Tighten up REFBF and REFTF decoupling layout
    [planewatcher.kicad_pcb]
2026-07-03 Improve analog supply decoupling and ground stitching
    - Reposition 3V3A decoupling and clean up nearby supply routing
    - Add GND stitching around ADC clock, reference/VOCM, and analog rail areas
    - Add extra ground returns near sensitive analog/noise-floor routing
    - Refill copper zones after the layout changes
    [planewatcher.kicad_pcb]
2026-07-08 Try to reduce ADC analog supply/reference noise
    - add ferrite beads to ADC and analog regulator supply rails
    - power ADC digital rail from FPGA 3V3 instead of local analog 3V3
    - tighten AD9203 VREF/REFTF/REFBF bypass layout
    - add selectable 0Ω REFSENSE links for 1 Vpp/2 Vpp ADC range
    - move noise-sensitive ADC/reference components and improve local stitching
    - remove crowded passive silkscreen reference text
    - update schematic sheet markup and notes
    [ADC.kicad_sch, ADC_Driver.kicad_sch, GPS_Module.kicad_sch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]
2026-07-08 Improve PCB grounding and sensitive-node isolation
    - add dense GND via stitching across the carrier PCB
    - reduce LT3045 SET trace width and remove the SET copper pour
    - add F.Cu copper-pour keepout around the ADL5513 CLPF node
    - tidy LED7/LED8 silkscreen reference placement
    - update PCB date and refresh proto 1.3 render
    [planewatcher.kicad_pcb]
2026-07-09 Improve readme for proto 1.3 design and add OSHW logo
    - clarify prototype status and describe current hardware architecture
    - document ADC, baseline filtering, timing, power, and grounding changes
    - link the software and FPGA gateware repository
    - clarify CERN-OHL-S licensing terms
    - add the Open Source Hardware logo to the README and PCB silkscreen
    [ADC_Driver.kicad_sch, planewatcher.kicad_pcb]
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2026-07-19 Routing changes
    - Swap AINP/AINN connections and reroute the differential pair to remove vias and crossovers. The ADC output will need to be adjusted in software to compensate.
    - Reposition input components and add skew tuning to differential pair.
    - Re-route 3V3 lines to not pass underneath sensitive VOCM components/traces.
    - Expand ground-via stitching and refresh copper pours.
    - Update silkscreen artwork and design dates.
    - Refresh render in readme
    [ADC.kicad_sch, ADC_Driver.kicad_sch, GPS_Module.kicad_sch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]
2026-07-19 Add 16kb I2C EEPROM
    - SCL to FPGA D15
    - SDA to FPGA E15
    - Write protect via solder jumper
    [eeprom.kicad_sch, planewatcher.kicad_pcb, planewatcher.kicad_sch]
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2026-07-25 Add RF pi matching networks + more
    - Remove EEPROM write project solder jumper
    - Update proto 1.3 documentation
    [ADC_Driver.kicad_sch, LNA_Stage.kicad_sch, Log_Detector.kicad_sch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]
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2026-07-26 fix: remove remnants of old solder jumper for R/W protection on EEPROM
    [planewatcher.kicad_pcb]
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2026-07-26 Fix C1 part number from 0402 to 0603 footprint
    [adsboost.kicad_pcb, adsboost.kicad_sch]
2026-07-31 feat(planewatcher): revise rev 1.3 ADC buffer stages
    - replace the OPA2320 with separate ADA4807-1 and OPA320 buffers
    - update schematics, symbols, PCB placement, and routing
    - refresh the op-amp datasheets
    - document the new buffer architecture and update the board render
    [ADC_Driver.kicad_sch, GPS_Module.kicad_sch, LNA_Stage.kicad_sch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]
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2026-07-31 add six 10 nF C0G return-path capacitors to spare Bank 33 pins
    - move the Bank 33 and Bank 35 headers into dedicated schematic sheets
    - update the PCB routing and project configuration
    - preserve the original physical positions of J4 and J5
    [fpga_headers_bank_33.kicad_sch, fpga_headers_bank_35.kicad_sch, planewatcher.kicad_pcb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]
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2026-09-26 Add rev 1.3 frontend sensitivity finding and evidence
    The rev 1.3 receiver was about 3 dB less sensitive than a Mode-S Beast on the
    same conducted stimulus. The cause was the preamble detector's absolute power
    threshold and 32 us holdoff, not the RF frontend. power_threshold 700 with an
    8 us holdoff brings the conducted knee to within 0.5 dB of the Beast. On air,
    median max range per bearing rose from 76 km to 164 km, roughly level with a
    Radarcape that used the same site. Includes the curated sweep, counter and
    coverage data, the plots, the analysis scripts, and a short record of what
    was ruled out.
    Coverage data is reduced to bearing, range and altitude; no site or aircraft
    coordinates ar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

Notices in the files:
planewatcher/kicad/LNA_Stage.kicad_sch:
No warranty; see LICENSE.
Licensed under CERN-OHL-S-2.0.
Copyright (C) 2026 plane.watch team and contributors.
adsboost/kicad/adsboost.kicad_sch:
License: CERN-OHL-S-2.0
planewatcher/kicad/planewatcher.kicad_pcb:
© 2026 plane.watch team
